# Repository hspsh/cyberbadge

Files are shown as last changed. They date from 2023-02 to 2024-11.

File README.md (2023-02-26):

# cyberbadge

Pin definitions:

| Name | Pin | Description
| --- | --- | ---
| ESP_BOOT_B1 | 0 | Sleep / User button 1 / boot into programming mode
| PROG_TX | 1 | 
| PROG_RX | 3 | 
| LIPO_VMEAS  | 15 | Connected to LiPo voltage behind 2/3 divider
| WS_OUT | 22 | WS2812 output pin
| ESP_B2 | 26 | User button 2 / boot alternative firmware
| ESP_B3 | 25 | User button 3

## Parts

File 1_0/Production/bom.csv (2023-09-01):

Comment | Designator | Footprint | LCSC
47uF/handsolder | C5 | Capacitor_SMD:C_1210_3225Metric_Pad1.33x2.70mm_HandSolder | C576521
100n | C6,C11,C12,C13,C14,C15,C16,C17,C18,C19,C20,C21,C22,C23,C24,C25,C26,C27,C28,C29,C30,C31,C32,C33,C34,C35,C36,C37,C38,C39,C40,C41,C42,C43,C44,C45,C46,C47,C48,C49,C50,C51,C52,C53,C54,C55,C56,C57,C58,C59,C60,C61,C62,C63,C64,C65,C66,C67,C68,C69,C70,C71,C72,C73,C74,C75,C76,C77,C78,C79,C80,C81,C82,C83,C84,C85,C86,C87,C88,C89,C90,C91,C92,C93,C94,C95,C96,C97,C98,C99,C100,C101,C102,C103,C104,C105,C106,C107,C108,C109,C110,C111,C112,C113,C114,C115,C116,C117,C118,C119,C120,C121,C122,C123,C124,C125,C126,C127,C128,C129,C130,C131,C132,C133,C134,C135,C136,C137,C138,C139,C140,C141,C142,C143,C144,C145,C146,C147,C148,C149,C150,C151,C152,C153,C154,C155,C156,C157,C158,C159,C160,C161,C162,C163,C164,C165,C166,C167,C168,C169,C170,C171,C172,C173,C174,C175,C176,C177,C178,C180,C181,C182,C183,C184,C185,C186,C187,C188,C189,C190,C191,C192,C193,C194,C195,C196,C197,C198,C199,C200,C201,C202,C203,C204,C205,C206,C207,C208,C209,C210,C211,C212,C213,C214,C215,C216,C217,C218,C219,C220,C221,C222,C223,C224,C225,C226,C227,C228,C229,C230,C231,C232,C233,C234,C235,C236,C237,C238,C239,C240,C241,C242,C243,C244,C245,C246,C247,C248,C249,C250,C251,C252,C253,C254,C255,C256,C257,C258,C259,C260,C261,C262,C263,C264,C265,C266,C267,C268,C269,C270,C271 | Capacitor_SMD:C_0201_0603Metric | C1525
4.7u | C7,C8,C9,C10,C179 | Capacitor_SMD:C_0402_1005Metric | C23733
LED | D1,D3,D4 | LED_SMD:LED_0603_1608Metric | C72038
WS2812B | D5,D6,D7,D8,D9,D10,D11,D12,D13,D14,D15,D16,D17,D18,D19,D20,D21,D22,D23,D24,D25,D26,D27,D28,D29,D30,D31,D32,D33,D34,D35,D36,D37,D38,D39,D40,D41,D42,D43,D44,D45,D46,D47,D48,D49,D50,D51,D52,D53,D54,D55,D56,D57,D58,D59,D60,D61,D62,D63,D64,D65,D66,D67,D68,D69,D70,D71,D72,D73,D74,D75,D76,D77,D78,D79,D80,D81,D82,D83,D84,D85,D86,D87,D88,D89,D90,D91,D92,D93,D94,D95,D96,D97,D98,D99,D100,D101,D102,D103,D104,D105,D106,D107,D108,D109,D110,D111,D112,D113,D114,D115,D116,D117,D118,D119,D120,D121,D122,D123,D124,D125,D126,D127,D128,D129,D130,D131,D132,D133,D134,D135,D136,D137,D138,D139,D140,D141,D142,D143,D144,D145,D146,D147,D148,D149,D150,D151,D152,D153,D154,D155,D156,D157,D158,D159,D160,D161,D162,D163,D164,D165,D166,D167,D168,D169,D170,D171,D172,D173,D174,D175,D176,D177,D178,D179,D180,D181,D182,D183,D184,D185,D186,D187,D188,D189,D190,D191,D192,D193,D194,D195,D196,D197,D198,D199,D200,D201,D202,D203,D204,D205,D206,D207,D208,D209,D210,D211,D212,D213,D214,D215,D216,D217,D218,D219,D220,D221,D222,D223,D224,D225,D226,D227,D228,D229,D230,D231,D232,D233,D234,D235,D236,D237,D238,D239,D240,D241,D242,D243,D244,D245,D246,D247,D248,D249,D250,D251,D252,D253,D254,D255,D256,D257,D258,D259,D260 | Critbit_lib:LED_WS2812B-2020_pinsRenumbered | C2976072
3A/slowblow | F1 | Fuse:Fuse_0603_1608Metric_Pad1.05x0.95mm_HandSolder | C553913
USB_C_Receptacle_USB2.0 | J1 | Connector_USB:USB_C_Receptacle_HRO_TYPE-C-31-M-12 | C165948
FS8205A | Q3 | Package_SO:TSSOP-8_4.4x3mm_P0.65mm | C16052
AO3401A | Q4,Q5 | Package_TO_SOT_SMD:SOT-23 | C15127
10k | R1,R2,R3,R6,R7,R8,R10,R14,R15,R18,R21 | Resistor_SMD:R_0201_0603Metric | C106225
2k | R16,R17 | Resistor_SMD:R_0603_1608Metric_Pad0.98x0.95mm_HandSolder | C22975
200 | R19 | Resistor_SMD:R_0201_0603Metric | C270359
1k | R20 | Resistor_SMD:R_0201_0603Metric | C138165
5.1k | R4,R5 | Resistor_SMD:R_0201_0603Metric | C473460
0R | R9,R11,R13 | Resistor_SMD:R_0603_1608Metric_Pad0.98x0.95mm_HandSolder | C2889381
B2 | SW1,SW5 | Button_Switch_SMD:SW_SPST_TL3342 | C318884
B1/BOOT | SW2 | Button_Switch_SMD:SW_SPST_TL3342 | C318884
SW_SPDT | SW3 | Button_Switch_SMD:SW_SPDT_PCM12 | C431541
ESP32-WROOM-32 | U3 | RF_Module:ESP32-WROOM-32 | C701342
SPX3819M5-L-3-3 | U4 | Package_TO_SOT_SMD:SOT-23-5 | C9055
BQ24073RGT | U5 | Package_DFN_QFN:VQFN-16-1EP_3x3mm_P0.5mm_EP1.6x1.6mm_ThermalVias | C15220
DW01x | U6 | Package_TO_SOT_SMD:SOT-23-6 | C351410

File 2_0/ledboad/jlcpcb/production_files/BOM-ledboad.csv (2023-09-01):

Comment | Designator | Footprint | LCSC
FM6126 | RU1,RU2,RU3,RU4,RU5,RU6 | SSOP-24_3.9x8.7mm_P0.635mm | C121618
AO3401A | Q1,Q2,Q3,Q4,Q5,Q6,Q7,Q8 | SOT-23 | C15127
100n | C1,C3 | C_0402_1005Metric | C1525
510 | R10,R11,R12,R13,R14,R9 | R_0402_1005Metric | C25123
10k | R1,R15,R16,R17,R2,R3,R4,R5,R6,R7,R8 | R_0402_1005Metric | C25744
LED_RGBA | D0_1,D0_2,D0_3,D0_4,D0_5,D0_6,D0_7,D0_8,D1,D10_1,D10_2,D10_3,D10_4,D10_5,D10_6,D10_7,D10_8,D11_1,D11_2,D11_3,D11_4,D11_5,D11_6,D11_7,D11_8,D12_1,D12_2,D12_3,D12_4,D12_5,D12_6,D12_7,D12_8,D13_1,D13_2,D13_3,D13_4,D13_5,D13_6,D13_7,D13_8,D14_1,D14_2,D14_3,D14_4,D14_5,D14_6,D14_7,D14_8,D15_1,D15_2,D15_3,D15_4,D15_5,D15_6,D15_7,D15_8,D16_1,D16_2,D16_3,D16_4,D16_5,D16_6,D16_7,D16_8,D17_1,D17_2,D17_3,D17_4,D17_5,D17_6,D17_7,D17_8,D18_1,D18_2,D18_3,D18_4,D18_5,D18_6,D18_7,D18_8,D19_1,D19_2,D19_3,D19_4,D19_5,D19_6,D19_7,D19_8,D1_1,D1_2,D1_3,D1_4,D1_5,D1_6,D1_7,D1_8,D20_1,D20_2,D20_3,D20_4,D20_5,D20_6,D20_7,D20_8,D21_1,D21_2,D21_3,D21_4,D21_5,D21_6,D21_7,D21_8,D22_1,D22_2,D22_3,D22_4,D22_5,D22_6,D22_7,D22_8,D23_1,D23_2,D23_3,D23_4,D23_5,D23_6,D23_7,D23_8,D24_1,D24_2,D24_3,D24_4,D24_5,D24_6,D24_7,D24_8,D25_1,D25_2,D25_3,D25_4,D25_5,D25_6,D25_7,D25_8,D26_1,D26_2,D26_3,D26_4,D26_5,D26_6,D26_7,D26_8,D27_1,D27_2,D27_3,D27_4,D27_5,D27_6,D27_7,D27_8,D28_1,D28_2,D28_3,D28_4,D28_5,D28_6,D28_7,D28_8,D29_1,D29_2,D29_3,D29_4,D29_5,D29_6,D29_7,D29_8,D2_1,D2_2,D2_3,D2_4,D2_5,D2_6,D2_7,D2_8,D30_1,D30_2,D30_3,D30_4,D30_5,D30_6,D30_7,D30_8,D31_1,D31_2,D31_3,D31_4,D31_5,D31_6,D31_7,D31_8,D3_1,D3_2,D3_3,D3_4,D3_5,D3_6,D3_7,D3_8,D4_1,D4_2,D4_3,D4_4,D4_5,D4_6,D4_7,D4_8,D5_1,D5_2,D5_3,D5_4,D5_5,D5_6,D5_7,D5_8,D6_1,D6_2,D6_3,D6_4,D6_5,D6_6,D6_7,D6_8,D7_1,D7_2,D7_3,D7_4,D7_5,D7_6,D7_7,D7_8,D8_1,D8_2,D8_3,D8_4,D8_5,D8_6,D8_7,D8_8,D9_1,D9_2,D9_3,D9_4,D9_5,D9_6,D9_7,D9_8 | 0606 | C2874115
2016/DNP | Y1 | Crystal_SMD_2016-4Pin_2.0x1.6mm | C3013592
10p/DNP | C7,C8 | C_0402_1005Metric | C32949
470n | C10,C2,C4,C5 | C_0402_1005Metric | C47339
STM32G070CBTx | U1 | LQFP-48_7x7mm_P0.5mm | C529338
XC6206PxxxMR | U2 | SOT-23-3 | C5446
TP | TP5 | TestPoint_Pad_D1.0mm
TP | TP7 | TestPoint_Pad_D1.0mm
TP | TP9 | TestPoint_Pad_D1.0mm
TP | TP28 | TestPoint_Pad_D1.0mm
TP | TP30 | TestPoint_Pad_D1.0mm
TP | TP31 | TestPoint_Pad_D1.0mm
TP | TP15 | TestPoint_Pad_D1.0mm
TP | TP6 | TestPoint_Pad_D1.0mm
TP | TP12 | TestPoint_Pad_D1.0mm
TP | TP29 | TestPoint_Pad_D1.0mm
TP | TP10 | TestPoint_Pad_D1.0mm
TP | TP24 | TestPoint_Pad_D1.0mm
TP | TP13 | TestPoint_Pad_D1.0mm
TP | TP26 | TestPoint_Pad_D1.0mm
TP | TP18 | TestPoint_Pad_D1.0mm
TP | TP19 | TestPoint_Pad_D1.0mm
TP | TP8 | TestPoint_Pad_D1.0mm
TP | TP16 | TestPoint_Pad_D1.0mm
TP | TP22 | TestPoint_Pad_D1.0mm
TP | TP21 | TestPoint_Pad_D1.0mm
TP | TP11 | TestPoint_Pad_D1.0mm
TP | TP25 | TestPoint_Pad_D1.0mm
TP | TP4 | TestPoint_Pad_D1.0mm
TP | TP17 | TestPoint_Pad_D1.0mm
TP | TP14 | TestPoint_Pad_D1.0mm
TP | TP2 | TestPoint_Pad_D1.0mm
TP | TP1 | TestPoint_Pad_D1.0mm
TP | TP27 | TestPoint_Pad_D1.0mm
TP | TP3 | TestPoint_Pad_D1.0mm
TP | TP23 | TestPoint_Pad_D1.0mm
TP | TP20 | TestPoint_Pad_D1.0mm
TP | TP32 | TestPoint_Pad_D1.0mm

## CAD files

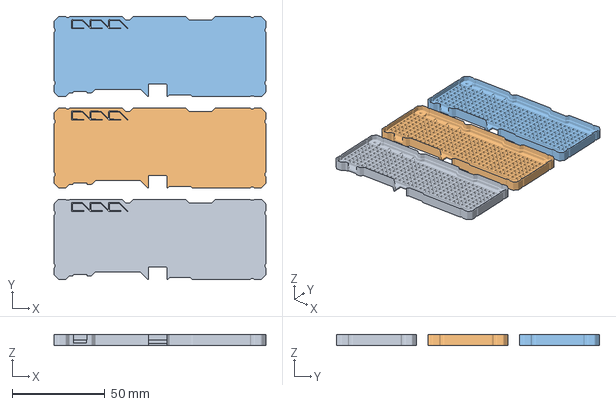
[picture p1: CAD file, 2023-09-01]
1_0/3d/diffuser.3mf
114.3 x 141.9 x 6.00 mm

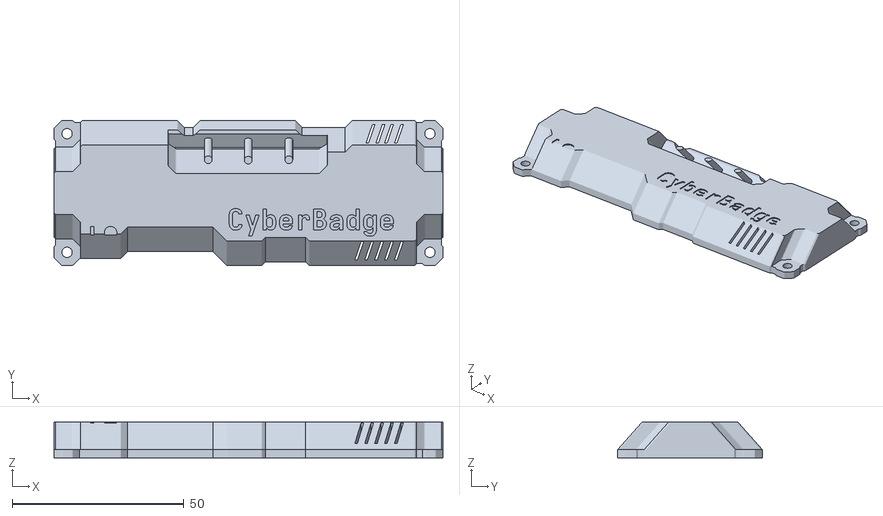
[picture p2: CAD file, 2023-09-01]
1_0/3d/filament/backcover-fat.stl
113.1 x 42.1 x 10.4

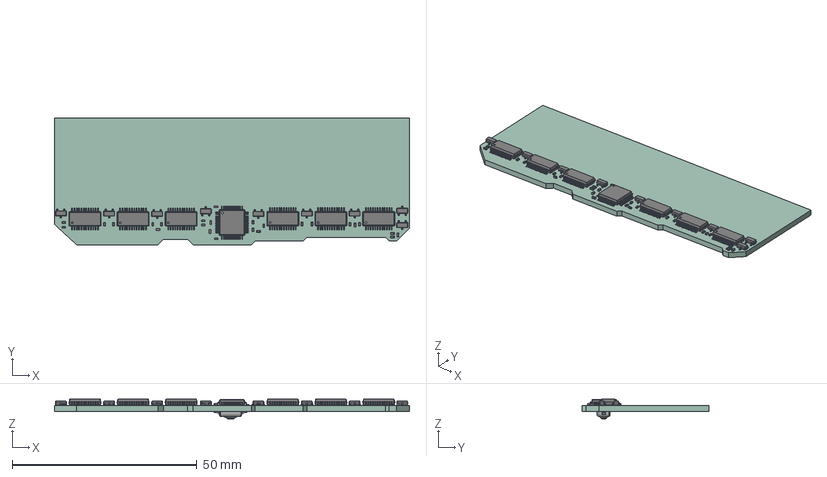
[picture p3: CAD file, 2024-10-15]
2_0/ledboad/ledboad.step
96.0 x 34.2 x 5.35 mm
SSOP_24_39x87mm_P0635mm x 6
LQFP_48_7x7mm_P05mm
SOT_23 x 8
R_0402_1005Metric x 17
C_0402_1005Metric x 8
SOT-23-3
ASSEMBLY
ledboad_PCB

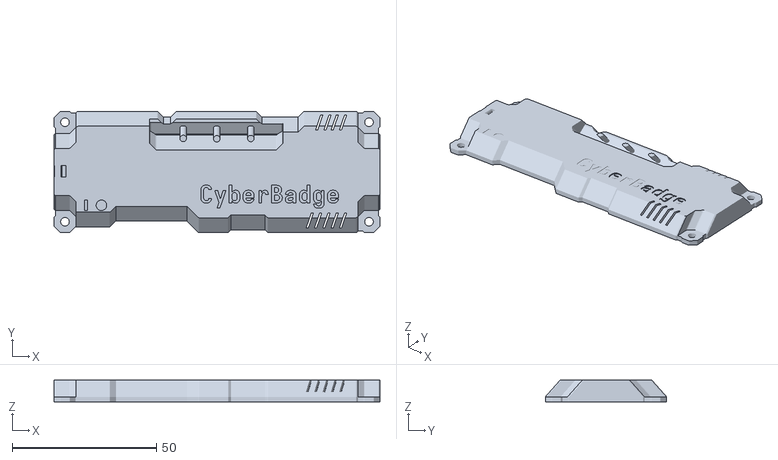
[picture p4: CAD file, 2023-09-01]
1_0/3d/filament/backcover_notch.stl
113.1 x 42.1 x 7.60

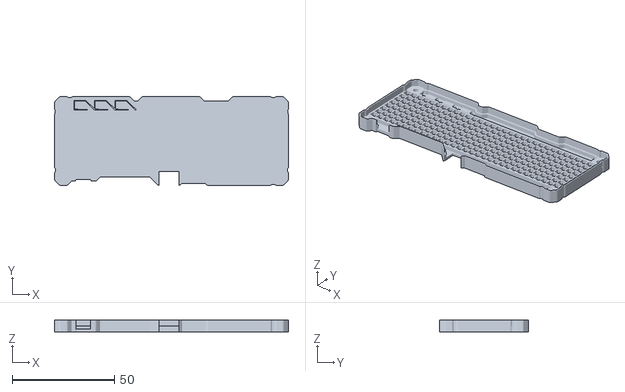
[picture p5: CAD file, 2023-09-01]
1_0/3d/filament/diffuser.stl
114.3 x 43.3 x 6.00

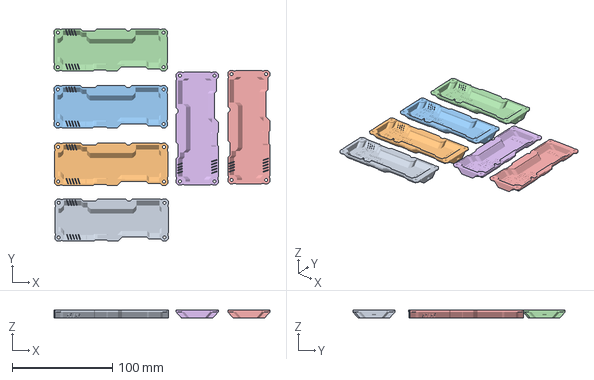
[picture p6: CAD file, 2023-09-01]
1_0/3d/filament/backcover m3.3mf
215.4 x 211.8 x 7.60 mm
backcover.stl x 6

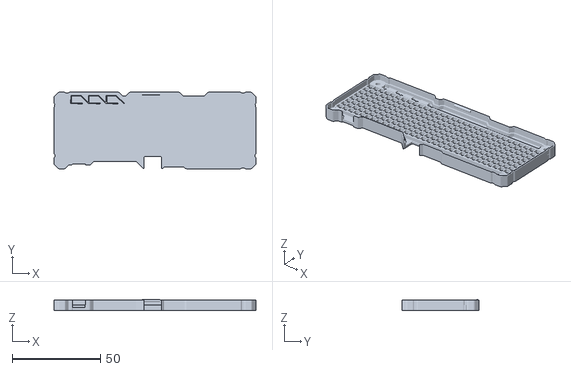
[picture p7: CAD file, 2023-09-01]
1_0/3d/filament/diffuser_notch.stl
114.3 x 43.3 x 6.10

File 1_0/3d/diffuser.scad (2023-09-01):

E = 0.6;  // Extruder dia.
L = 0.3;  // Layer height

N = 8;    // X LEDs
M = 32;   // Y LEDs

pitch = 0.350 * 10;  // dist. between leds

h = N * pitch;
w = M * pitch;

led_h = pitch;
led_w = pitch;


face_height = L*3;  // transparent diffuser face
pcb_height = 3; // PCB dist from diffures
height = pcb_height + 3;
button_height = 3 - 1.6 - 0.4;

has_holder = false;

module pcb () {
    color("green") offset(r=0.3) import("outline.svg");
}

module model () {
    #translate([65.9,110,1+pcb_height]) rotate([0,180,0]) import("model.stl");
}

module usb () {
    color("red") offset(r=0.3) import("usb.svg");
}

module switch () {
    color("red") import("switch.svg");
}


module holder () {
    color("red") offset(r=0.3) import("holder.svg");
}

module holder_holes () {
    color("red") import("holder_holes.svg");
}

module buttons () {
    color("red") offset(r=-0) import("buttons.svg");
}

module buttons_area () {
    color("red") offset(r=-0) import("buttons_area.svg");
}

module holes() {
    offset(r=-0.1) import("holes.svg");
}

module holes_standoffs () {
    color("orange") difference () {
        offset(r=1.8) import("holes.svg");
        offset(r=-0.4) import("holes.svg");
    }
}

module led() {
    square([led_w, led_h]);
}

matrix_x = 9.85;
matrix_y = 9.55;

module matrix_courtyard () {
    offset(-E/2) translate([matrix_x, matrix_y]) square([w, h]);
    //import("matrix_courtyard.svg");
}


module matrix_diffuser () {

    translate([matrix_x,matrix_y])
    for (j = [0:M-1]) {
    for (i = [0:N-1]) {
        translate([j * led_w, i * led_h, 0]) offset(r=-E/2) led();
    }
    }
    
    
}

module outer_outline(r=E) {
    offset(r=r) pcb();
}

module cover() {

    difference() {
        union() {
            linear_extrude(face_height+L)
            difference () {
                outer_outline();
                matrix_courtyard();
            }

            
            linear_extrude(pcb_height)
            union() {
                difference() {
                    outer_outline();
                    offset(r=-1) pcb();
                }
                holes_standoffs();
                offset(E*2) matrix_courtyard();
            }
            
            linear_extrude(height)
            difference() {
                outer_outline();
                pcb(); 
            }
            
        }
        color("yellow") linear_extrude(pcb_height+1)
        matrix_diffuser();
    }
    
    linear_extrude(pcb_height-button_height) color("red") buttons_area();
        
    linear_extrude(face_height) {
        matrix_courtyard();
    }
    if (!has_holder) {
        linear_extrude(face_height+L) offset(-0.5) holder();
        //linear_extrude(height+2) offset(0.4)holder_holes();
    }
}

module faceplate() {
    mirror([1,0,0]) difference () {
        color("white") cover();
        linear_extrude(height) color("red") usb();
        translate([0,0,pcb_height-1.5]) linear_extrude(5) color("red") switch();  
        if (has_holder) linear_extrude(height) color("red") holder();
        linear_extrude(height) color("red") offset(-0.2) buttons();
        //translate([18, 3.3]) linear_extrude(L) text("CyberBadge 1.0.0", size=3, font="Iosevka");
    }
}
module notch () {
translate([-73,43.5,5.4]) rotate([0,90,0]) cylinder(10,r=0.7,true, $fn=20);
}


//cover();
//model();
//faceplate();
//notch();

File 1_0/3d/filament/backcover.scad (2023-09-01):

include <diffuser.scad>

include <commit.scad>
/*skew takes an array of six angles:
 *x along y
 *x along z
 *y along x
 *y along z
 *z along x
 *z along y
 */
module skew(dims) {
matrix = [
	[ 1, dims[0]/45, dims[1]/45, 0 ],
	[ dims[2]/45, 1, dims[4]/45, 0 ],
	[ dims[5]/45, dims[3]/45, 1, 0 ],
	[ 0, 0, 0, 1 ]
];
multmatrix(matrix)
children();
}

height_back = 6*L;
hl = 5.8;

back_wall_w = 1;

module mounts_courtyard() {
    color("green") offset(r=0.4) import("mounts_courtyard.svg");
}

module holder_courtyard() {
    color("green") offset(r=0.4) import("holder_courtyard.svg");
}

module internal_supports() {
    color("green") import("internal_supports.svg");
}

module idontknow() {
    difference() {
        pcb();
        mounts_courtyard();
    }
}



module idontknow_extruded(off=0) {
    a = 40;
    intersection() {
        skew([0, 0, 0, 0, a, 0]) linear_extrude(hl) offset(off) idontknow();
        skew([0, 0, 0, 0, -a, 0]) linear_extrude(hl) offset(off)idontknow();
    }
}

module insidespace (){
    difference () {
        translate([0,0,-2*L]) idontknow_extruded(-2*E);

        linear_extrude(100, center=true) internal_supports();
    }
}

module angled_holder() {
    skew([0, 0, 0, 0, -40, 0]) linear_extrude(hl) 
        offset(0.4) holder_holes();
    intersection() {
        cube([100,100,3.]);
        skew([0, 0, 0, 0, -40, 0]) linear_extrude() pcb();
        skew([0, 0, 0, 0, 60, 0]) linear_extrude() holder_courtyard();
    }
}
module back_structure() {
    difference() {
        union() {
            linear_extrude(height_back) pcb();
            translate([0,0,height_back]) idontknow_extruded();
        }
        translate([0,0,1.5]) insidespace();
        linear_extrude(1.5) projection() insidespace();
        linear_extrude(.7) offset(.3) import("esp.svg");
    }   
    if (!has_holder) {
        translate([0,0,height_back]) angled_holder();   
    }
}

module backplate() {
    translate([0,0,height]) mirror([1,0,0]) {
        difference() {
            back_structure();
            linear_extrude() color("red") holes();
            translate([36, 4,0]) mirror([1,0,0]) linear_extrude() 
                text("/////", size=4, font="Iosevka:style=Extrabold Extended");
            translate([36, 38,0]) mirror([1,0,0]) linear_extrude() 
                text(" ////", size=4, font="Iosevka:style=Extrabold Extended");
            if (has_holder) linear_extrude(height) color("red") holder();
            translate([72, 12,height_back+hl-L]) mirror([1,0,0]) linear_extrude(L*2, true) 
                text("CyberBadge", size=6, font="Iosevka:style=Bold Extended");
            translate([0,0,height_back+hl-L]) linear_extrude(L*2, true) 
                import("onoff.svg");
            
            // strap hole
            translate([121,25,height_back+hl-1]) rotate([90,0,0]) difference() {
                cylinder(h=4, d=6, $fn=30);
                cylinder(h=10, d=3, $fn=30);
            }
            author_size = 4.5;
            author_height = hl + .7;
            translate([20,31,author_height]) linear_extrude(2*L) 
                text("2023", size=author_size, font="Iosevka:style=Extended");
            translate([20,24,author_height]) linear_extrude(2*L) 
                text("sf: Goggi", size=author_size, font="Iosevka:style=Extended");
            translate([20,17,author_height]) linear_extrude(2*L) 
                text("hw: cr1tbit", size=author_size, font="Iosevka:style=Extended");
            translate([20,10,author_height]) linear_extrude(2*L) 
                text("3d: not7CD", size=author_size, font="Iosevka:style=Extended");
            if(commit) {
                translate([105,36,author_height]) rotate([0,0,-90]) linear_extrude(2*L) 
                    text(commit, size=author_size, font="Iosevka:style=Extended");
            }
        }
    }
}



//#color("grey") faceplate();
difference() {
backplate();
    translate([0,.2,1.2]) notch();
}

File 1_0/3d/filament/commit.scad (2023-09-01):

commit="c5ee4d9";

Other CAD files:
1_0/3d/filament/backcover.3mf
1_0/3d/filament/diffuser.scad
1_0/3d/filament/backcover.stl
1_0/3d/resin/diffuser.scad

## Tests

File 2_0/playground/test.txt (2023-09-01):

(symbol (lib_id "Device:LED_RGBA") (at 0.0 0.0 180) (unit 1)
    (in_bom yes) (on_board yes) (dnp no) (fields_autoplaced)
    (uuid b5239acb-de3e-4381-ac19-cf19dd583ec6)
    (property "Reference" "D0_0" (at 0.0 -9.0 0)
        (effects (font (size 1.27 1.27)))
    )
    (property "Value" "LED_RGBA" (at 0.0 -7.0 0)
        (effects (font (size 1.27 1.27)))
    )
    (property "Footprint" "" (at 0.0 -1.0 0)
        (effects (font (size 1.27 1.27)) hide)
    )
    (property "Datasheet" "~" (at 0.0 -1.0 0)
        (effects (font (size 1.27 1.27)) hide)
    )
    (pin "1" (uuid 9afb940c-849e-4cc7-8221-d7bd8efa1177))
    (pin "2" (uuid 9dc256f7-8ff4-4ee1-883c-a23038607fed))
    (pin "3" (uuid 3aa06f76-7f2f-492b-819e-7da5531ed259))
    (pin "4" (uuid cecc442f-c784-43b3-b2a9-1cc1a514e606))
    (instances
        (project "led-panel-DCHY-P2-644-1515-VP"
            (path "/5db5c9dc-e71f-4239-bd71-746a78d23540"
                (reference "D0_0") (unit 1)
            )
        )
        (project "playground"
            (path "/bbdec91f-f69a-4b77-89e2-e7db0a42527e"
                (reference "D0_0") (unit 1)
            )
        )
    )
)
(symbol (lib_id "Device:LED_RGBA") (at 17.78 0.0 180) (unit 1)
    (in_bom yes) (on_board yes) (dnp no) (fields_autoplaced)
    (uuid 7c8bd5e9-99b7-4953-934b-2639a43ec68f)
    (property "Reference" "D1_0" (at 17.78 -9.0 0)
        (effects (font (size 1.27 1.27)))
    )
    (property "Value" "LED_RGBA" (at 17.78 -7.0 0)
        (effects (font (size 1.27 1.27)))
    )
    (property "Footprint" "" (at 17.78 -1.0 0)
        (effects (font (size 1.27 1.27)) hide)
    )
    (property "Datasheet" "~" (at 17.78 -1.0 0)
        (effects (font (size 1.27 1.27)) hide)
    )
    (pin "1" (uuid aa416f67-d0b2-45b0-9154-dd5afe01cff5))
    (pin "2" (uuid 643edd00-fd95-428d-a0bf-0b5d1236c766))
    (pin "3" (uuid 6826ec87-7cba-42d3-9d5b-8df7166d4794))
    (pin "4" (uuid 81f33f3e-a824-4fb8-ba8d-c1d81a93cd0a))
    (instances
        (project "led-panel-DCHY-P2-644-1515-VP"
            (path "/5db5c9dc-e71f-4239-bd71-746a78d23540"
                (reference "D1_0") (unit 1)
            )
        )
        (project "playground"
            (path "/bbdec91f-f69a-4b77-89e2-e7db0a42527e"
                (reference "D1_0") (unit 1)
            )
        )
    )
)
(symbol (lib_id "Device:LED_RGBA") (at 35.56 0.0 180) (unit 1)
    (in_bom yes) (on_board yes) (dnp no) (fields_autoplaced)
    (uuid 7b71219f-20d2-4035-9a9c-44744254e7f7)
    (property "Reference" "D2_0" (at 35.56 -9.0 0)
        (effects (font (size 1.27 1.27)))
    )
    (property "Value" "LED_RGBA" (at 35.56 -7.0 0)
        (effects (font (size 1.27 1.27)))
    )
    (property "Footprint" "" (at 35.56 -1.0 0)
        (effects (font (size 1.27 1.27)) hide)
    )
    (property "Datasheet" "~" (at 35.56 -1.0 0)
        (effects (font (size 1.27 1.27)) hide)
    )
    (pin "1" (uuid 90450bbe-ebfe-4208-87f5-95e08b2e7b3a))
    (pin "2" (uuid eeb8c861-fb5f-4005-9317-84928848e821))
    (pin "3" (uuid b5e12993-0491-447c-96b4-13ae09ea5589))
    (pin "4" (uuid a5530a0e-5ab4-4921-bd41-d1c1ca5cab11))
    (instances
        (project "led-panel-DCHY-P2-644-1515-VP"
            (path "/5db5c9dc-e71f-4239-bd71-746a78d23540"
                (reference "D2_0") (unit 1)
            )
        )
        (project "playground"
            (path "/bbdec91f-f69a-4b77-89e2-e7db0a42527e"
                (reference "D2_0") (unit 1)
            )
        )
    )
)
(symbol (lib_id "Device:LED_RGBA") (at 53.34 0.0 180) (unit 1)
    (in_bom yes) (on_board yes) (dnp no) (fields_autoplaced)
    (uuid bb58695b-2069-4632-bfae-99d2b3c03046)
    (property "Reference" "D3_0" (at 53.34 -9.0 0)
        (effects (font (size 1.27 1.27)))
    )
    (property "Value" "LED_RGBA" (at 53.34 -7.0 0)
        (effects (font (size 1.27 1.27)))
    )
    (property "Footprint" "" (at 53.34 -1.0 0)
        (effects (font (size 1.27 1.27)) hide)
    )
    (property "Datasheet" "~" (at 53.34 -1.0 0)
        (effects (font (size 1.27 1.27)) hide)
    )
    (pin "1" (uuid 41f23ed1-db7e-4fde-a7bd-7a3c4968526a))
    (pin "2" (uuid 2ea46015-cc32-4960-acc0-870741be18e0))
    (pin "3" (uuid 3d3d402a-1e60-4032-a4dd-b1bd28b92f42))
    (pin "4" (uuid 3bf58e80-705b-4883-bb5a-dcb5eeae0c60))
    (instances
        (project "led-panel-DCHY-P2-644-1515-VP"
            (path "/5db5c9dc-e71f-4239-bd71-746a78d23540"
                (reference "D3_0") (unit 1)
            )
        )
        (project "playground"
            (path "/bbdec91f-f69a-4b77-89e2-e7db0a42527e"
                (reference "D3_0") (unit 1)
            )
        )
    )
)
(symbol (lib_id "Device:LED_RGBA") (at 71.12 0.0 180) (unit 1)
    (in_bom yes) (on_board yes) (dnp no) (fields_autoplaced)
    (uuid 9e8b6c33-7c1f-4225-b098-66206fa557b0)
    (property "Reference" "D4_0" (at 71.12 -9.0 0)
        (effects (font (size 1.27 1.27)))
    )
    (property "Value" "LED_RGBA" (at 71.12 -7.0 0)
        (effects (font (size 1.27 1.27)))
    )
    (property "Footprint" "" (at 71.12 -1.0 0)
        (effects (font (size 1.27 1.27)) hide)
    )
    (property "Datasheet" "~" (at 71.12 -1.0 0)
        (effects (font (size 1.27 1.27)) hide)
    )
    (pin "1" (uuid 6168f4e9-d6ef-46dd-8a9a-06a26dfb000c))
    (pin "2" (uuid e317d715-ac64-40d4-806d-1ae71ec9ac4a))
    (pin "3" (uuid 34e0e496-cd19-4eec-8b63-f1335cf79731))
    (pin "4" (uuid 6fbcbc87-ce8a-4eed-b284-7ffb7634b786))
    (instances
        (project "led-panel-DCHY-P2-644-1515-VP"
            (path "/5db5c9dc-e71f-4239-bd71-746a78d23540"
                (reference "D4_0") (unit 1)
            )
        )
        (project "playground"
            (path "/bbdec91f-f69a-4b77-89e2-e7db0a42527e"
                (reference "D4_0") (unit 1)
            )
        )
    )
)
(symbol (lib_id "Device:LED_RGBA") (at 88.9 0.0 180) (unit 1)
    (in_bom yes) (on_board yes) (dnp no) (fields_autoplaced)
    (uuid c8d675de-aac9-431b-8d95-032ddd7acad7)
    (property "Reference" "D5_0" (at 88.9 -9.0 0)
        (effects (font (size 1.27 1.27)))
    )
    (property "Value" "LED_RGBA" (at 88.9 -7.0 0)
        (effects (font (size 1.27 1.27)))
    )
    (property "Footprint" "" (at 88.9 -1.0 0)
        (effects (font (size 1.27 1.27)) hide)
    )
    (property "Datasheet" "~" (at 88.9 -1.0 0)
        (effects (font (size 1.27 1.27)) hide)
    )
    (pin "1" (uuid 6f9dadc0-3249-4db3-893e-b0fa2a9106dd))
    (pin "2" (uuid 9febca0d-c065-42e7-860a-2320ac044ce0))
    (pin "3" (uuid 70a6024f-67f3-4fbc-9193-a65a6cfd7ae9))
    (pin "4" (uuid dee9dd2b-dff2-47ea-b24c-edf9b3cbe2cb))
    (instances
        (project "led-panel-DCHY-P2-644-1515-VP"
            (path "/5db5c9dc-e71f-4239-bd71-746a78d23540"
                (reference "D5_0") (unit 1)
            )
        )
        (project "playground"
            (path "/bbdec91f-f69a-4b77-89e2-e7db0a42527e"
                (reference "D5_0") (unit 1)
            )
        )
    )
)
(symbol (lib_id "Device:LED_RGBA") (at 106.68 0.0 180) (unit 1)
    (in_bom yes) (on_board yes) (dnp no) (fields_autoplaced)
    (uuid 2e2d61c4-fce4-42c1-80a6-a3d129ac2fc6)
    (property "Reference" "D6_0" (at 106.68 -9.0 0)
        (effects (font (size 1.27 1.27)))
    )
    (property "Value" "LED_RGBA" (at 106.68 -7.0 0)
        (effects (font (size 1.27 1.27)))
    )
    (property "Footprint" "" (at 106.68 -1.0 0)
        (effects (font (size 1.27 1.27)) hide)
    )
    (property "Datasheet" "~" (at 106.68 -1.0 0)
        (effects (font (size 1.27 1.27)) hide)
    )
    (pin "1" (uuid 59a1e3ae-a2fd-483b-b5f8-33efda59f700))
    (pin "2" (uuid 33c5be9b-62bb-4e88-83cd-481750cd52fc))
    (pin "3" (uuid 21321528-2ff3-48bd-97b8-fca021fb2f60))
    (pin "4" (uuid a4fefea4-8cdf-493a-aed2-c6e82a4cefcd))
    (instances
        (project "led-panel-DCHY-P2-644-1515-VP"
            (path "/5db5c9dc-e71f-4239-bd71-746a78d23540"
                (reference "D6_0") (unit 1)
            )
        )
        (project "playground"
            (path "/bbdec91f-f69a-4b77-89e2-e7db0a42527e"
                (reference "D6_0") (unit 1)
            )
        )
    )
)
(symbol (lib_id "Device:LED_RGBA") (at 124.46000000000001 0.0 180) (unit 1)
    (in_bom yes) (on_board yes) (dnp no) (fields_autoplaced)
    (uuid d1ec0869-f101-4db6-9e30-9709fad659bf)
    (property "Reference" "D7_0" (at 124.46000000000001 -9.0 0)
        (effects (font (size 1.27 1.27)))
    )
    (property "Value" "LED_RGBA" (at 124.46000000000001 -7.0 0)
        (effects (font (size 1.27 1.27)))
    )
    (property "Footprint" "" (at 124.46000000000001 -1.0 0)
        (effects (font (size 1.27 1.27)) hide)
    )
    (property "Datasheet" "~" (at 124.46000000000001 -1.0 0)
        (effects (font (size 1.27 1.27)) hide)
    )
    (pin "1" (uuid 71e733a9-78e8-4f1f-9b2d-95b119712e44))
    (pin "2" (uuid a3836047-629b-454a-aab0-2aabc785c4fd))
    (pin "3" (uuid e436dbd9-7f8d-4e15-9798-4c785a735863))
    (pin "4" (uuid e7f6f756-beb1-4a5c-8868-ace6c9972639))
    (instances
        (project "led-panel-DCHY-P2-644-1515-VP"
            (path "/5db5c9dc-e71f-4239-bd71-746a78d23540"
                (reference "D7_0") (unit 1)
            )
        )
        (project "playground"
            (path "/bbdec91f-f69a-4b77-89e2-e7db0a42527e"
                (reference "D7_0") (unit 1)
            )
        )
    )
)
(symbol (lib_id "Device:LED_RGBA") (at 142.24 0.0 180) (unit 1)
    (in_bom yes) (on_board yes) (dnp no) (fields_autoplaced)
    (uuid 18135223-a771-47a8-9ad9-08793206c02e)
    (property "Reference" "D8_0" (at 142.24 -9.0 0)
        (effects (font (size 1.27 1.27)))
    )
    (property "Value" "LED_RGBA" (at 142.24 -7.0 0)
        (effects (font (size 1.27 1.27)))
    )
    (property "Footprint" "" (at 142.24 -1.0 0)
        (effects (font (size 1.27 1.27)) hide)
    )
    (property "Datasheet" "~" (at 142.24 -1.0 0)
        (effects (font (size 1.27 1.27)) hide)
    )
    (pin "1" (uuid da6323c4-7ab3-4581-84cb-695a4334e879))
    (pin "2" (uuid d09bd3d1-8244-49f7-91e2-78c244229215))
    (pin "3" (uuid ad63bbe2-d447-4d80-9508-fc426798c51e))
    (pin "4" (uuid ef49bf94-098f-4b17-adb6-e532070caf88))
    (instances
        (project "led-panel-DCHY-P2-644-1515-VP"
            (path "/5db5c9dc-e71f-4239-bd71-746a78d23540"
                (reference "D8_0") (unit 1)
            )
        )
        (project "playground"
            (path "/bbdec91f-f69a-4b77-89e2-e7db0a42527e"
                (reference "D8_0") (unit 1)
            )
        )
    )
)
(symbol (lib_id "Device:LED_RGBA") (at 160.02 0.0 180) (unit 1)
    (in_bom yes) (on_board yes) (dnp no) (fields_autoplaced)
    (uuid 4b34109c-dba0-42f3-96b4-f39ca7909796)
    (property "Reference" "D9_0" (at 160.02 -9.0 0)
        (effects (font (size 1.27 1.27)))
    )
    (property "Value" "LED_RGBA" (at 160.02 -7.0 0)
        (effects (font (size 1.27 1.27)))
    )
    (property "Footprint" "" (at 160.02 -1.0 0)
        (effects (font (size 1.27 1.27)) hide)
    )
    (property "Datasheet" "~" (at 160.02 -1.0 0)
        (effects (font (size 1.27 1.27)) hide)
    )
    (pin "1" (uuid 86311450-1b60-4f4a-b7d7-0b5b1054a920))
    (pin "2" (uuid 144dfe6b-2bc3-440d-8526-588a9e9c6d56))
    (pin "3" (uuid e375f36c-7764-4cd0-bcad-5b4b0ed2f4ad))
    (pin "4" (uuid 5e89cbed-8687-4687-b9c3-fc662937045b))
    (instances
        (project "led-panel-DCHY-P2-644-1515-VP"
            (path "/5db5c9dc-e71f-4239-bd71-746a78d23540"
                (reference "D9_0") (unit 1)
            )
        )
        (project "playground"
            (path "/bbdec91f-f69a-4b77-89e2-e7db0a42527e"
                (reference "D9_0") (unit 1)
            )
        )
    )
)
(symbol (lib_id "Device:LED_RGBA") (at 177.8 0.0 180) (unit 1)
    (in_bom yes) (on_board yes) (dnp no) (fields_autoplaced)
    (uuid f1e571c2-d03c-4fbb-9026-2ebb28b5f4d9)
    (property "Reference" "D10_0" (at 177.8 -9.0 0)
        (effects (font (size 1.27 1.27)))
    )
    (property "Value" "LED_RGBA" (at 177.8 -7.0 0)
        (effects (font (size 1.27 1.27)))
    )
    (property "Footprint" "" (at 177.8 -1.0 0)
        (effects (font (size 1.27 1.27)) hide)
    )
    (property "Datasheet" "~" (at 177.8 -1.0 0)
        (effects (font (size 1.27 1.27)) hide)
    )
    (pin "1" (uuid 0ff5fb6b-ed1b-4bb6-b7c2-b8825612c12f))
    (pin "2" (uuid 8e362b1c-ddb5-4c50-a7ef-d50058fab5a4))
    (pin "3" (uuid 40563174-aa67-4698-a846-a652d011485c))
    (pin "4" (uuid b7262587-3ffa-463c-8c5a-ca303d3792f7))
    (instances
        (project "led-panel-DCHY-P2-644-1515-VP"
            (path "/5db5c9dc-e71f-4239-bd71-746a78d23540"
                (reference "D10_0") (unit 1)
            )
        )
        (project "playground"
            (path "/bbdec91f-f69a-4b77-89e2-e7db0a42527e"
                (reference "D10_0") (unit 1)
            )
        )
    )
)
(symbol (lib_id "Device:LED_RGBA") (at 195.58 0.0 180) (unit 1)
    (in_bom yes) (on_board yes) (dnp no) (fields_autoplaced)
    (uuid cfe18296-2c5f-4e39-9be0-daabf80e21db)
    (property "Reference" "D11_0" (at 195.58 -9.0 0)
        (effects (font (size 1.27 1.27)))
    )
    (property "Value" "LED_RGBA" (at 195.58 -7.0 0)
        (effects (font (size 1.27 1.27)))
    )
    (property "Footprint" "" (at 195.58 -1.0 0)
        (effects (font (size 1.27 1.27)) hide)
    )
    (property "Datasheet" "~" (at 195.58 -1.0 0)
        (effects (font (size 1.27 1.27)) hide)
    )
    (pin "1" (uuid cbfd824f-8265-434d-a061-ce314d1a17b8))
    (pin "2" (uuid 9c58c7f0-f652-4720-a50b-16176fcadcc8))
    (pin "3" (uuid cf3d79f7-6906-4955-846c-840bda8de959))
    (pin "4" (uuid 6f29a4dd-3184-4606-896a-7bde176deb74))
    (instances
        (project "led-panel-DCHY-P2-644-1515-VP"
            (path "/5db5c9dc-e71f-4239-bd71-746a78d23540"
                (reference "D11_0") (unit 1)
            )
        )
        (project "playground"
            (path "/bbdec91f-f69a-4b77-89e2-e7db0a42527e"
                (reference "D11_0") (unit 1)
            )
        )
    )
)
(symbol (lib_id "Device:LED_RGBA") (at 213.36 0.0 180) (unit 1)
    (in_bom yes) (on_board yes) (dnp no) (fields_autoplaced)
    (uuid 638cdb74-587b-4e95-9682-4d0ae17dec80)
    (property "Reference" "D12_0" (at 213.36 -9.0 0)
        (effects (font (size 1.27 1.27)))
    )
    (property "Value" "LED_RGBA" (at 213.36 -7.0 0)
        (effects (font (size 1.27 1.27)))
    )
    (property "Footprint" "" (at 213.36 -1.0 0)
        (effects (font (size 1.27 1.27)) hide)
    )
    (property "Datasheet" "~" (at 213.36 -1.0 0)
        (effects (font (size 1.27 1.27)) hide)
    )
    (pin "1" (uuid 63223616-e21e-4c1d-bde3-df72ff97d66a))
    (pin "2" (uuid 7d024b65-1be4-4a24-9f1f-e647cbf9387a))
    (pin "3" (uuid 93211b17-7d1a-4181-ae9f-f3df76b65c15))
    (pin "4" (uuid 66470455-c565-4bea-ac8b-f20666db9af4))
    (instances
        (project "led-panel-DCHY-P2-644-1515-VP"
            (path "/5db5c9dc-e71f-4239-bd71-746a78d23540"
                (reference "D12_0") (unit 1)
            )
        )
        (project "playground"
            (path "/bbdec91f-f69a-4b77-89e2-e7db0a42527e"
                (reference "D12_0") (unit 1)
            )
        )
    )
)
(symbol (lib_id "Device:LED_RGBA") (at 231.14000000000001 0.0 180) (unit 1)
    (in_bom yes) (on_board yes) (dnp no) (fields_autoplaced)
    (uuid 98803cc0-b2ad-4623-8544-0ee3b2ff0de2)
    (property "Reference" "D13_0" (at 231.14000000000001 -9.0 0)
        (effects (font (size 1.27 1.27)))
    )
    (property "Value" "LED_RGBA" (at 231.14000000000001 -7.0 0)
        (effects (font (size 1.27 1.27)))
    )
    (property "Footprint" "" (at 231.14000000000001 -1.0 0)
        (effects (font (size 1.27 1.27)) hide)
    )
    (property "Datasheet" "~" (at 231.14000000000001 -1.0 0)
        (effects (font (size 1.27 1.27)) hide)
    )
    (pin "1" (uuid a8911b86-052c-4c0d-aac0-253173e5f541))
    (pin "2" (uuid bad4a824-ad2e-40de-8734-d3950f4d59a7))
    (pin "3" (uuid 1606d09e-ccb2-4303-8fbf-3be10cbb1fc4))
    (pin "4" (uuid bdf62127-e66b-4f76-9d13-5da3df7d8c9a))
    (instances
        (project "led-panel-DCHY-P2-644-1515-VP"
            (path "/5db5c9dc-e71f-4239-bd71-746a78d23540"
                (reference "D13_0") (unit 1)
            )
        )
        (project "playground"
            (path "/bbdec91f-f69a-4b77-89e2-e7db0a42527e"
                (reference "D13_0") (unit 1)
            )
        )
    )
)
(symbol (lib_id "Device:LED_RGBA") (at 248.92000000000002 0.0 180) (unit 1)
    (in_bom yes) (on_board yes) (dnp no) (fields_autoplaced)
    (uuid 84c49366-4388-42bd-8da4-4313b0f25c47)
    (property "Reference" "D14_0" (at 248.92000000000002 -9.0 0)
        (effects (font (size 1.27 1.27)))
    )
    (property "Value" "LED_RGBA" (at 248.92000000000002 -7.0 0)
        (effects (font (size 1.27 1.27)))
    )
    (property "Footprint" "" (at 248.92000000000002 -1.0 0)
        (effects (font (size 1.27 1.27)) hide)
    )
    (property "Datasheet" "~" (at 248.92000000000002 -1.0 0)
        (effects (font (size 1.27 1.27)) hide)
    )
    (pin "1" (uuid 2a26a417-9a0d-4713-b4ac-c837cb0bb5ec))
    (pin "2" (uuid ef323cd7-0e29-4b2b-b5e3-87a4c2d5777e))
    (pin "3" (uuid d774bf9c-a55e-474d-b8e5-4e24857debea))
    (pin "4" (uuid 8b9993eb-0a33-4c20-8808-a22ce8c75ef1))
    (instances
        (project "led-panel-DCHY-P2-644-1515-VP"
            (path "/5db5c9dc-e71f-4239-bd71-746a78d23540"
                (reference "D14_0") (unit 1)
            )
        )
        (project "playground"
            (path "/bbdec91f-f69a-4b77-89e2-e7db0a42527e"
                (reference "D14_0") (unit 1)
            )
        )
    )
)
(symbol (lib_id "Device:LED_RGBA") (at 266.7 0.0 180) (unit 1)
    (in_bom yes) (on_board yes) (dnp no) (fields_autoplaced)
    (uuid 9ccb3a7a-08eb-4ec3-a898-c266fdd4fd63)
    (property "Reference" "D15_0" (at 266.7 -9.0 0)
        (effects (font (size 1.27 1.27)))
    )
    (property "Value" "LED_RGBA" (at 266.7 -7.0 0)
        (effects (font (size 1.27 1.27)))
    )
    (property "Footprint" "" (at 266.7 -1.0 0)
        (effects (font (size 1.27 1.27)) hide)
    )
    (property "Datasheet" "~" (at 266.7 -1.0 0)
        (effects (font (size 1.27 1.27)) hide)
    )
    (pin "1" (uuid fff66f1b-c549-4466-8a3b-5e141461b675))
    (pin "2" (uuid b22e888e-ead3-4d18-8611-3564d432eb0d))
    (pin "3" (uuid d8704b91-37c9-4f92-854c-1743acc43b54))
    (pin "4" (uuid b061771a-9e24-4e9d-a87f-50a11f47956f))
    (instances
        (project "led-panel-DCHY-P2-644-1515-VP"
            (path "/5db5c9dc-e71f-4239-bd71-746a78d23540"
                (reference "D15_0") (unit 1)
            )
        )
        (project "playground"
            (path "/bbdec91f-f69a-4b77-89e2-e7db0a42527e"
                (reference "D15_0") (unit 1)
            )
        )
    )
)
(symbol (lib_id "Device:LED_RGBA") (at 284.48 0.0 180) (unit 1)
    (in_bom yes) (on_board yes) (dnp no) (fields_autoplaced)
    (uuid ddc6de1c-22c0-49bd-8b3d-817b869bea74)
    (property "Reference" "D16_0" (at 284.48 -9.0 0)
        (effects (font (size 1.27 1.27)))
    )
    (property "Value" "LED_RGBA" (at 284.48 -7.0 0)
        (effects (font (size 1.27 1.27)))
    )
    (property "Footprint" "" (at 284.48 -1.0 0)
        (effects (font (size 1.27 1.27)) hide)
    )
    (property "Datasheet" "~" (at 284.48 -1.0 0)
        (effects (font (size 1.27 1.27)) hide)
    )
    (pin "1" (uuid b82faf44-342e-41fc-966f-651a9b69f147))
    (pin "2" (uuid 9e0516f6-473a-4eb1-82b1-c23d77248813))
    (pin "3" (uuid d674df32-7e0b-4478-a575-833059da752e))
    (pin "4" (uuid d0de94a7-82e9-44b9-ba54-d157095d2dca))
    (instances
        (project "led-panel-DCHY-P2-644-1515-VP"
            (path "/5db5c9dc-e71f-4239-bd71-746a78d23540"
                (reference "D16_0") (unit 1)
            )
        )
        (project "playground"
            (path "/bbdec91f-f69a-4b77-89e2-e7db0a42527e"
                (reference "D16_0") (unit 1)
            )
        )
    )
)
(symbol (lib_id "Device:LED_RGBA") (at 302.26 0.0 180) (unit 1)
    (in_bom yes) (on_board yes) (dnp no) (fields_autoplaced)
    (uuid 90ac0e00-6870-4570-bc46-e19dc795d811)
    (property "Reference" "D17_0" (at 302.26 -9.0 0)
        (effects (font (size 1.27 1.27)))
    )
    (property "Value" "LED_RGBA" (at 302.26 -7.0 0)
        (effects (font (size 1.27 1.27)))
    )
    (property "Footprint" "" (at 302.26 -1.0 0)
        (effects (font (size 1.27 1.27)) hide)
    )
    (property "Datasheet" "~" (at 302.26 -1.0 0)
        (effects (font (size 1.27 1.27)) hide)
    )
    (pin "1" (uuid 60225a18-0cba-47fb-83bc-2c44990057c8))
    (pin "2" (uuid 3731ceda-aa45-4800-a67a-8c1a606e73fd))
    (pin "3" (uuid c461aaa7-8ef4-4c70-a4c0-bcdfe24917ef))
    (pin "4" (uuid 89725172-08fc-4c04-b4ce-e1febaf1ae8a))
    (instances
        (project "led-panel-DCHY-P2-644-1515-VP"
            (path "/5db5c9dc-e71f-4239-bd71-746a78d23540"
                (reference "D17_0") (unit 1)
            )
        )
        (project "playground"
            (path "/bbdec91f-f69a-4b77-89e2-e7db0a42527e"
                (reference "D17_0") (unit 1)
            )
        )
    )
)
(symbol (lib_id "Device:LED_RGBA") (at 320.04 0.0 180) (unit 1)
    (in_bom yes) (on_board yes) (dnp no) (fields_autoplaced)
    (uuid 0bfcf3c9-ba43-4cd7-95e6-e1de87be6987)
    (property "Reference" "D18_0" (at 320.04 -9.0 0)
        (effects (font (size 1.27 1.27)))
    )
    (property "Value" "LED_RGBA" (at 320.04 -7.0 0)
        (effects (font (size 1.27 1.27)))
    )
    (property "Footprint" "" (at 320.04 -1.0 0)
        (effects (font (size 1.27 1.27)) hide)
    )
    (property "Datasheet" "~" (at 320.04 -1.0 0)
        (effects (font (size 1.27 1.27)) hide)
    )
    (pin "1" (uuid 263e1b26-9d17-406b-abb2-915ebaee7bf1))
    (pin "2" (uuid 6c0ff9fa-0da4-458e-8e8d-b5ae3ac570be))
    (pin "3" (uuid 603c080b-4f7f-41a3-9773-ca226aaaaebe))
    (pin "4" (uuid ed63254e-5149-4526-9a11-cf76332edeee))
    (instances
        (project "led-panel-DCHY-P2-644-1515-VP"
            (path "/5db5c9dc-e71f-4239-bd71-746a78d23540"
                (reference "D18_0") (unit 1)
            )
        )
        (project "playground"
            (path "/bbdec91f-f69a-4b77-89e2-e7db0a42527e"
                (reference "D18_0") (unit 1)
            )
        )
    )
)
(symbol (lib_id "Device:LED_RGBA") (at 337.82 0.0 180) (unit 1)
    (in_bom yes) (on_board yes) (dnp no) (fields_autoplaced)
    (uuid f86fa5d2-ac4e-473b-95d1-5ac095ec4e70)
    (property "Reference" "D19_0" (at 337.82 -9.0 0)
        (effects (font (size 1.27 1.27)))
    )
    (property "Value" "LED_RGBA" (at 337.82 -7.0 0)
        (effects (font (size 1.27 1.27)))
    )
    (property "Footprint" "" (at 337.82 -1.0 0)
        (effects (font (size 1.27 1.27)) hide)
    )
    (property "Datasheet" "~" (at 337.82 -1.0 0)
        (effects (font (size 1.27 1.27)) hide)
    )
    (pin "1" (uuid f6b88147-93e6-453b-9a11-9d283d1b4ba0))
    (pin "2" (uuid d8f40f04-914c-4b1c-ba11-125626c56eaa))
    (pin "3" (uuid 8a9d56b5-4863-44df-886b-579f3bdfd0d1))
    (pin "4" (uuid 93b979e5-1417-4a16-aa48-1cb4c1797752))
    (instances
        (project "led-panel-DCHY-P2-644-1515-VP"
            (path "/5db5c9dc-e71f-4239-bd71-746a78d23540"
                (reference "D19_0") (unit 1)
            )
        )
        (project "playground"
            (path "/bbdec91f-f69a-4b77-89e2-e7db0a42527e"
                (reference "D19_0") (unit 1)
            )
        )
    )
)
(symbol (lib_id "Device:LED_RGBA") (at 355.6 0.0 180) (unit 1)
    (in_bom yes) (on_board yes) (dnp no) (fields_autoplaced)
    (uuid 3527c40f-5bd6-4243-b007-aaa13ac5f0e1)
    (property "Reference" "D20_0" (at 355.6 -9.0 0)
        (effects (font (size 1.27 1.27)))
    )
    (property "Value" "LED_RGBA" (at 355.6 -7.0 0)
        (effects (font (size 1.27 1.27)))
    )
    (property "Footprint" "" (at 355.6 -1.0 0)
        (effects (font (size 1.27 1.27)) hide)
    )
    (property "Datasheet" "~" (at 355.6 -1.0 0)
        (effects (font (size 1.27 1.27)) hide)
    )
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

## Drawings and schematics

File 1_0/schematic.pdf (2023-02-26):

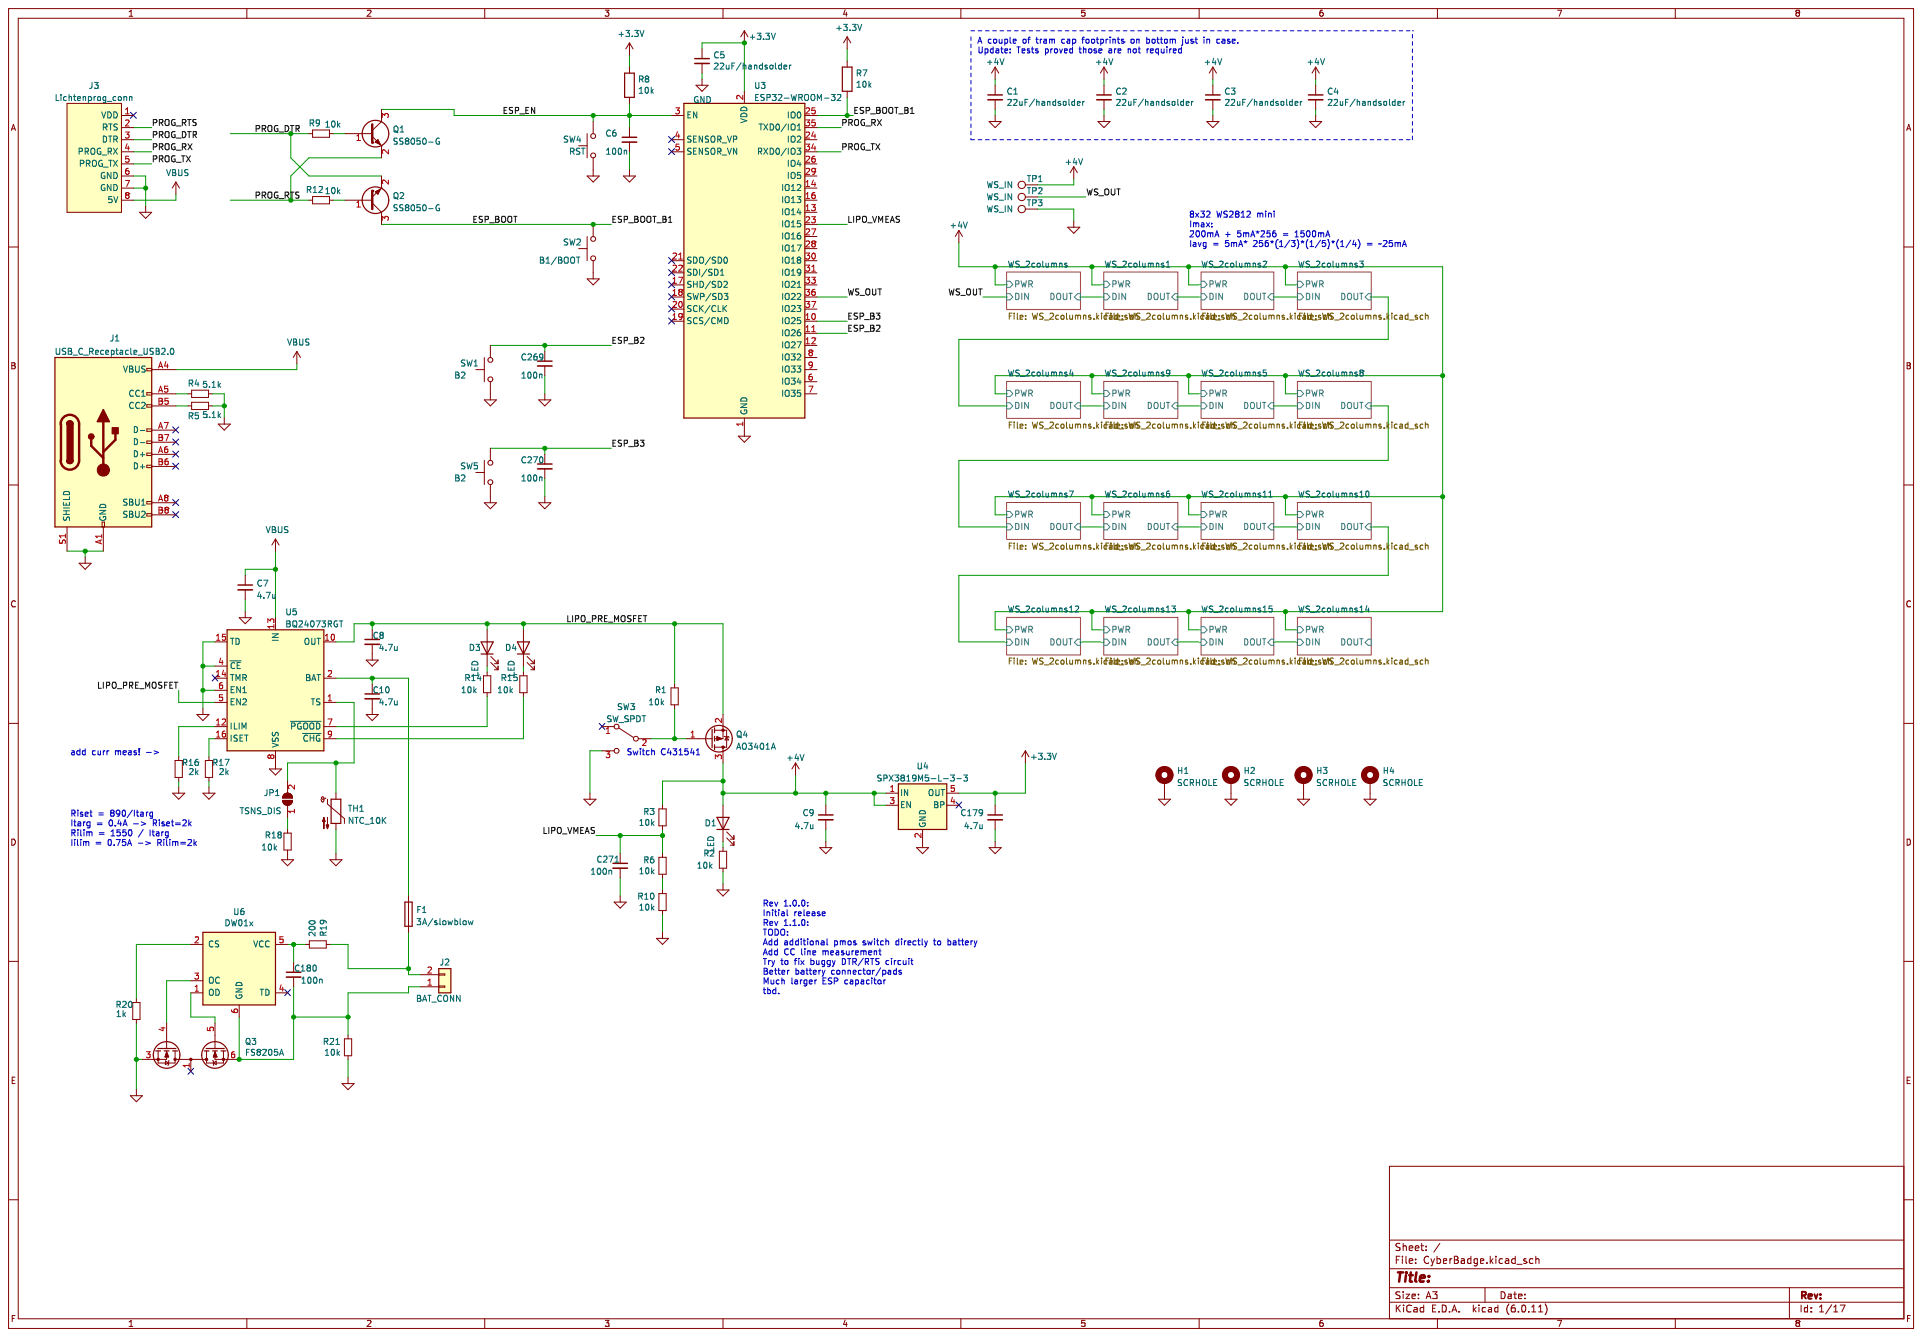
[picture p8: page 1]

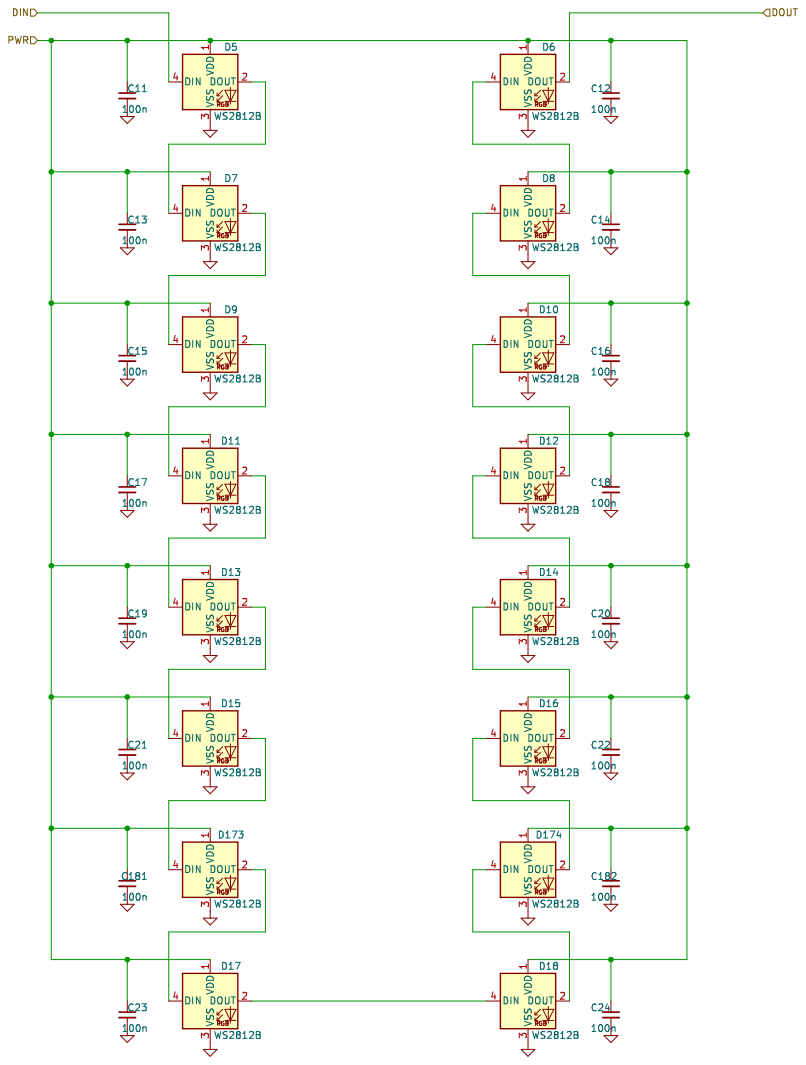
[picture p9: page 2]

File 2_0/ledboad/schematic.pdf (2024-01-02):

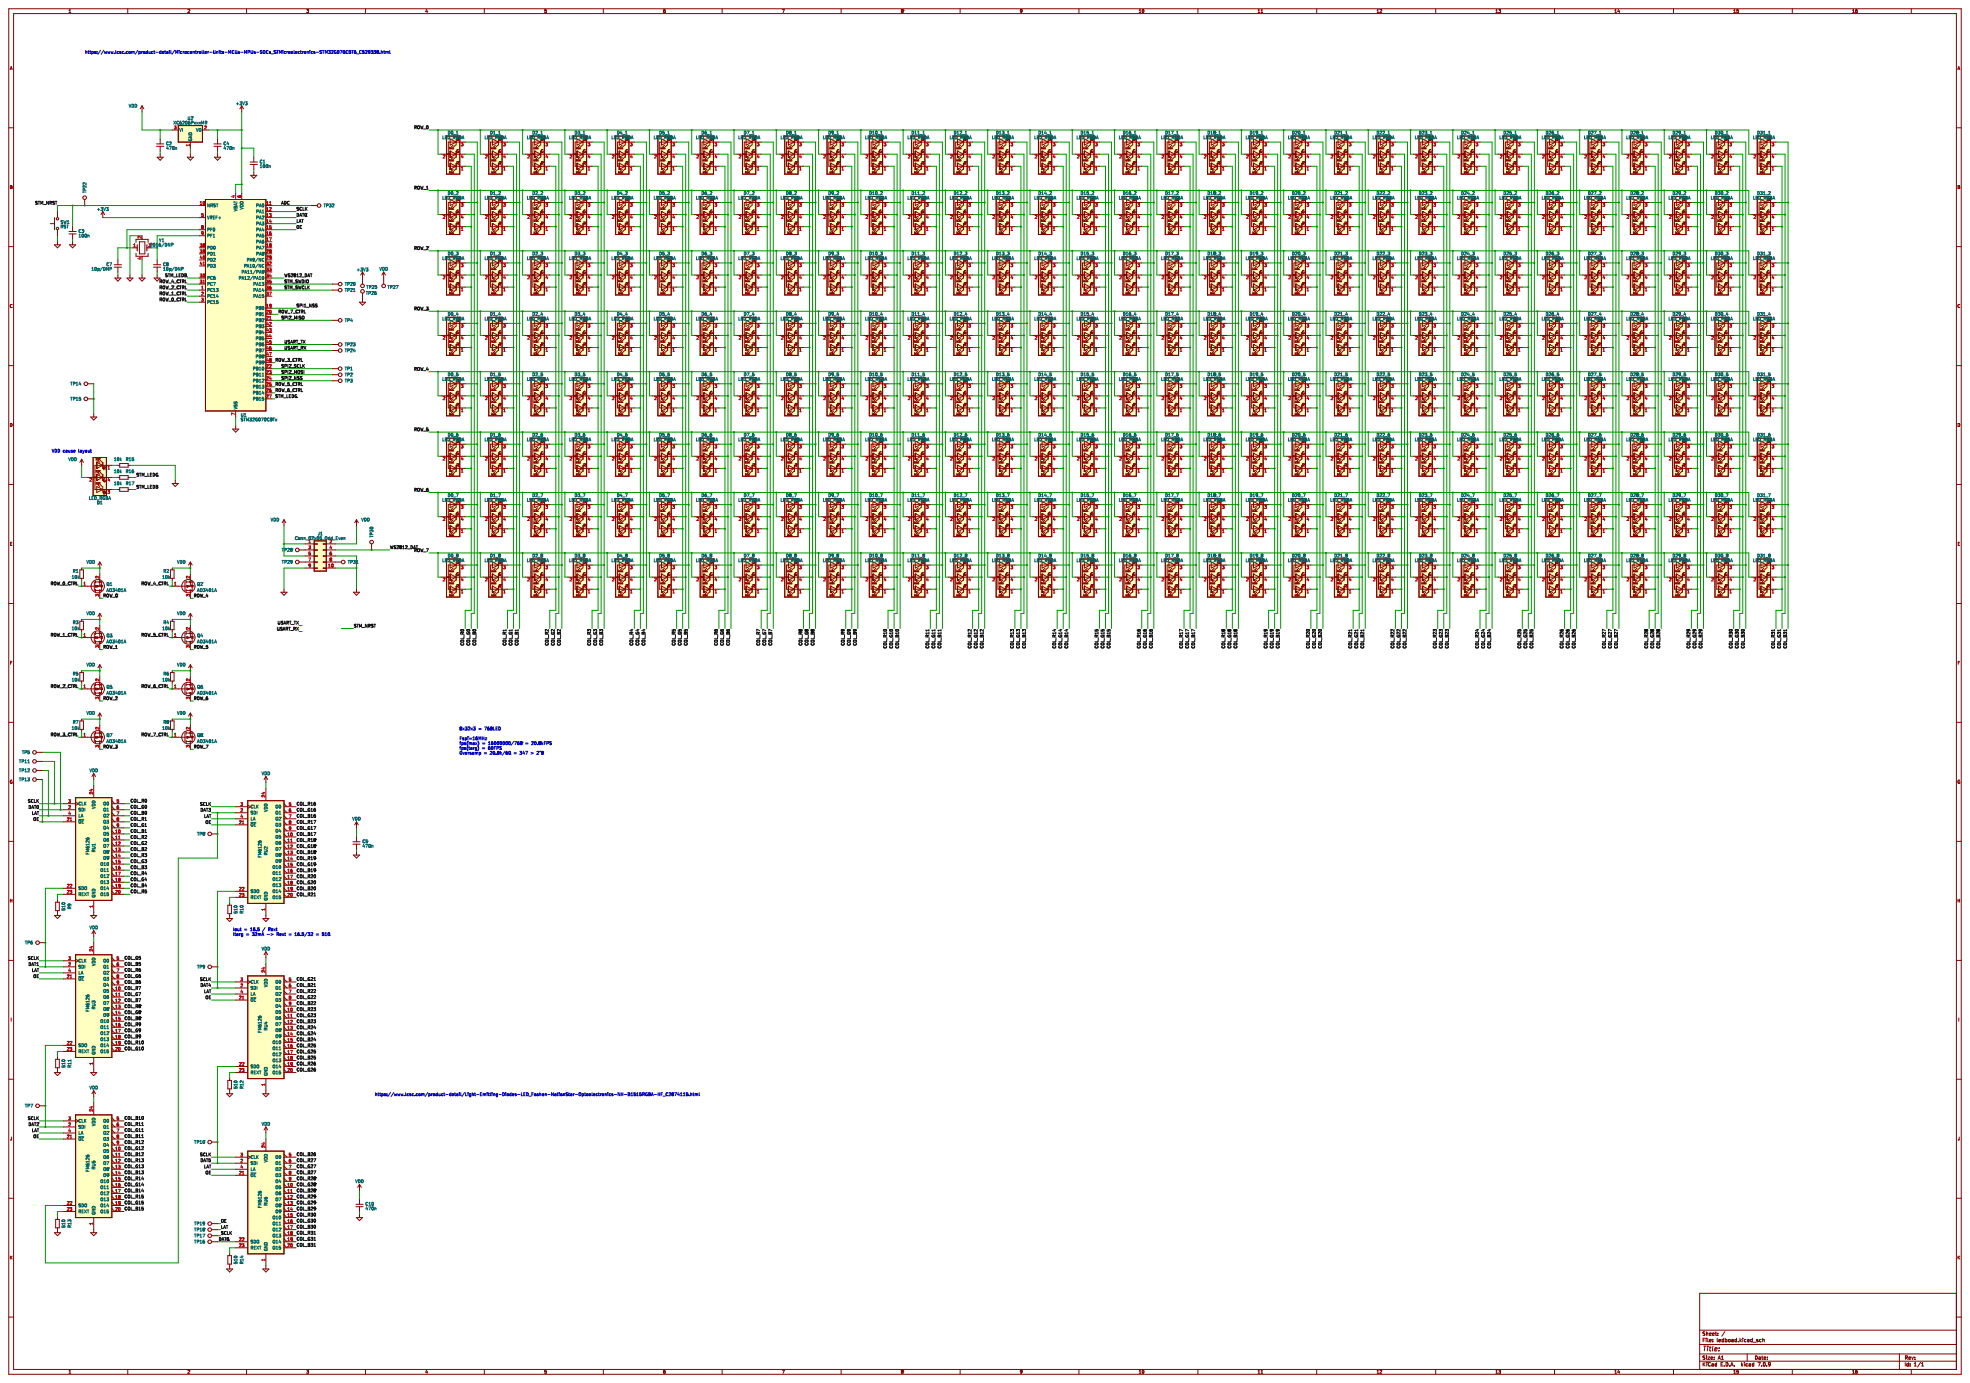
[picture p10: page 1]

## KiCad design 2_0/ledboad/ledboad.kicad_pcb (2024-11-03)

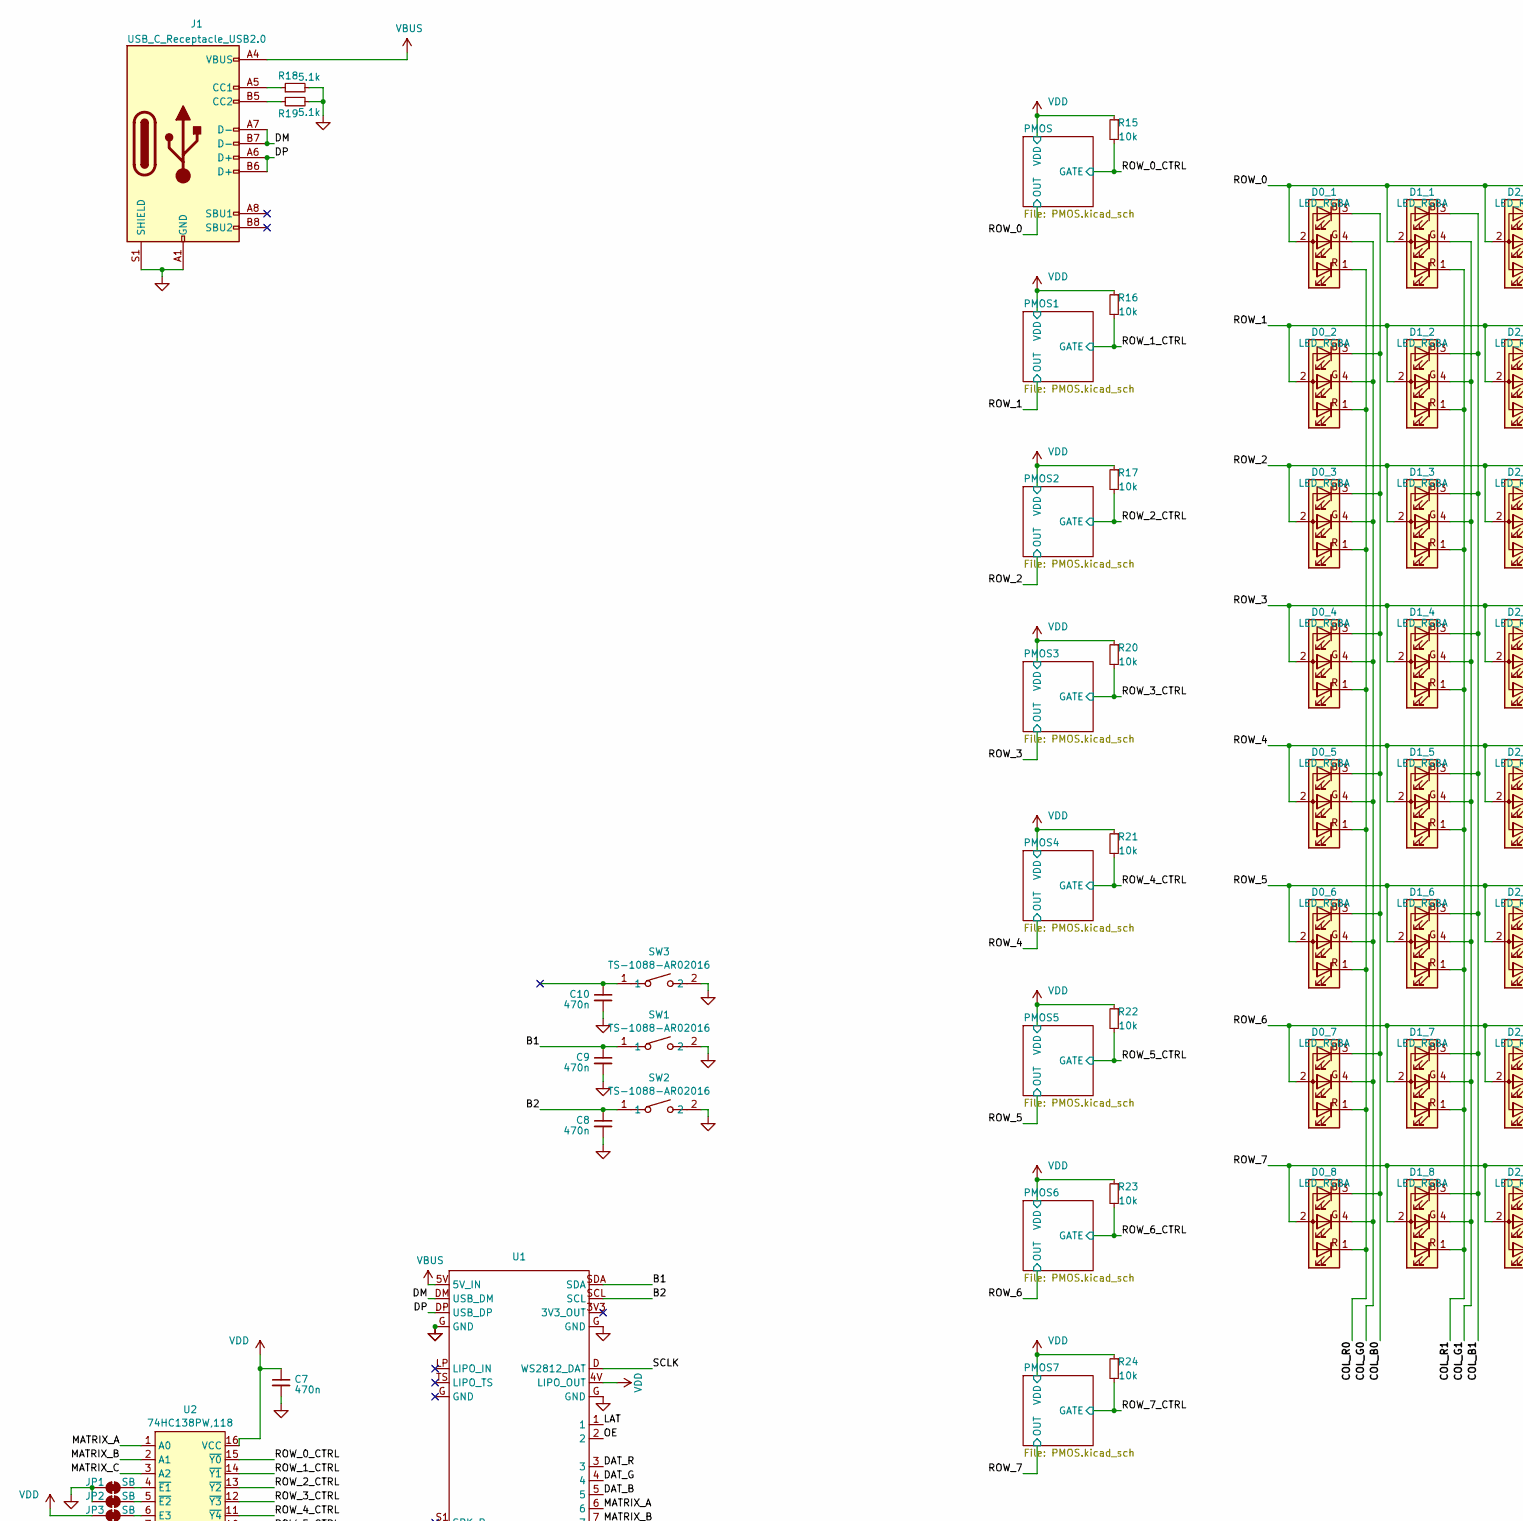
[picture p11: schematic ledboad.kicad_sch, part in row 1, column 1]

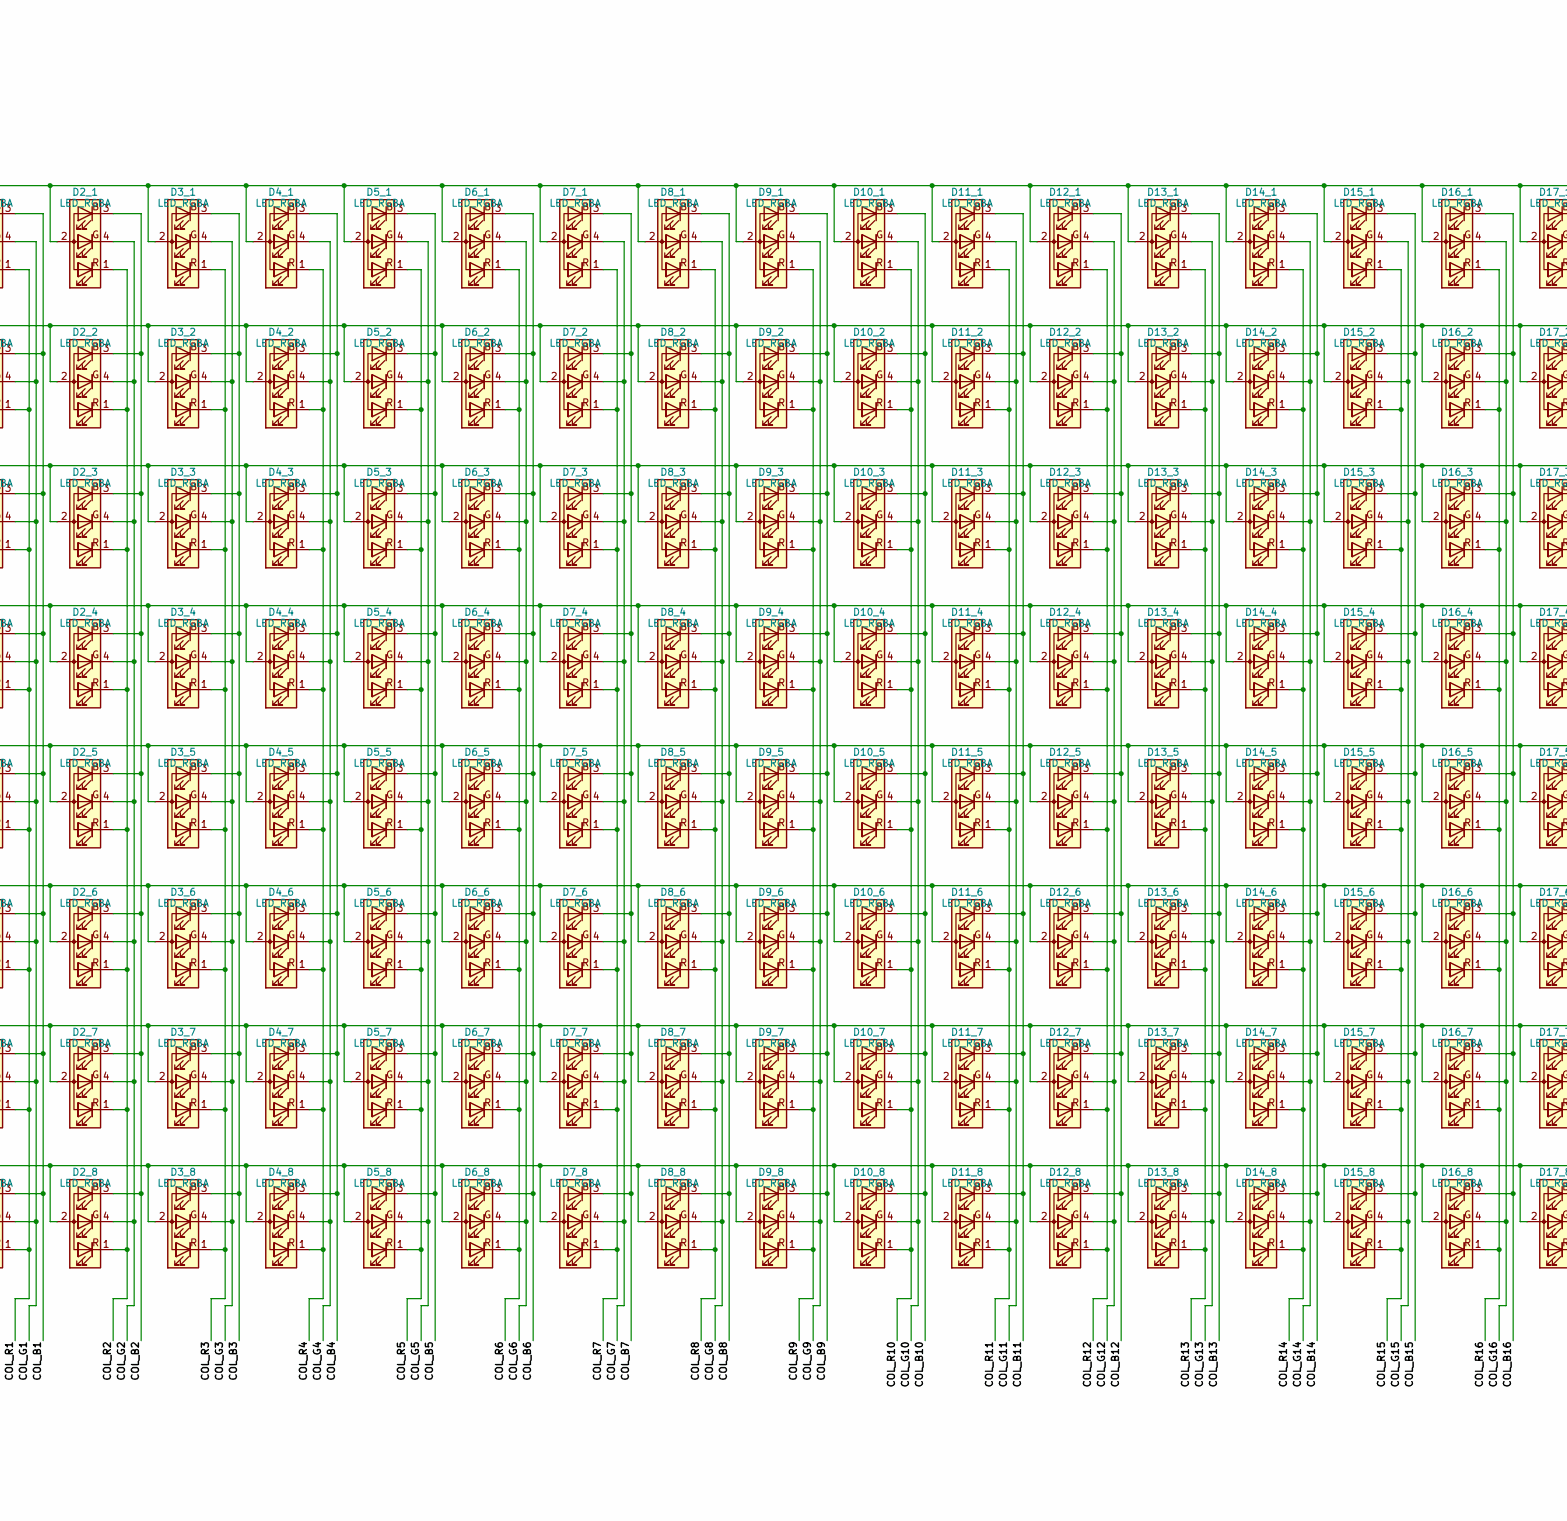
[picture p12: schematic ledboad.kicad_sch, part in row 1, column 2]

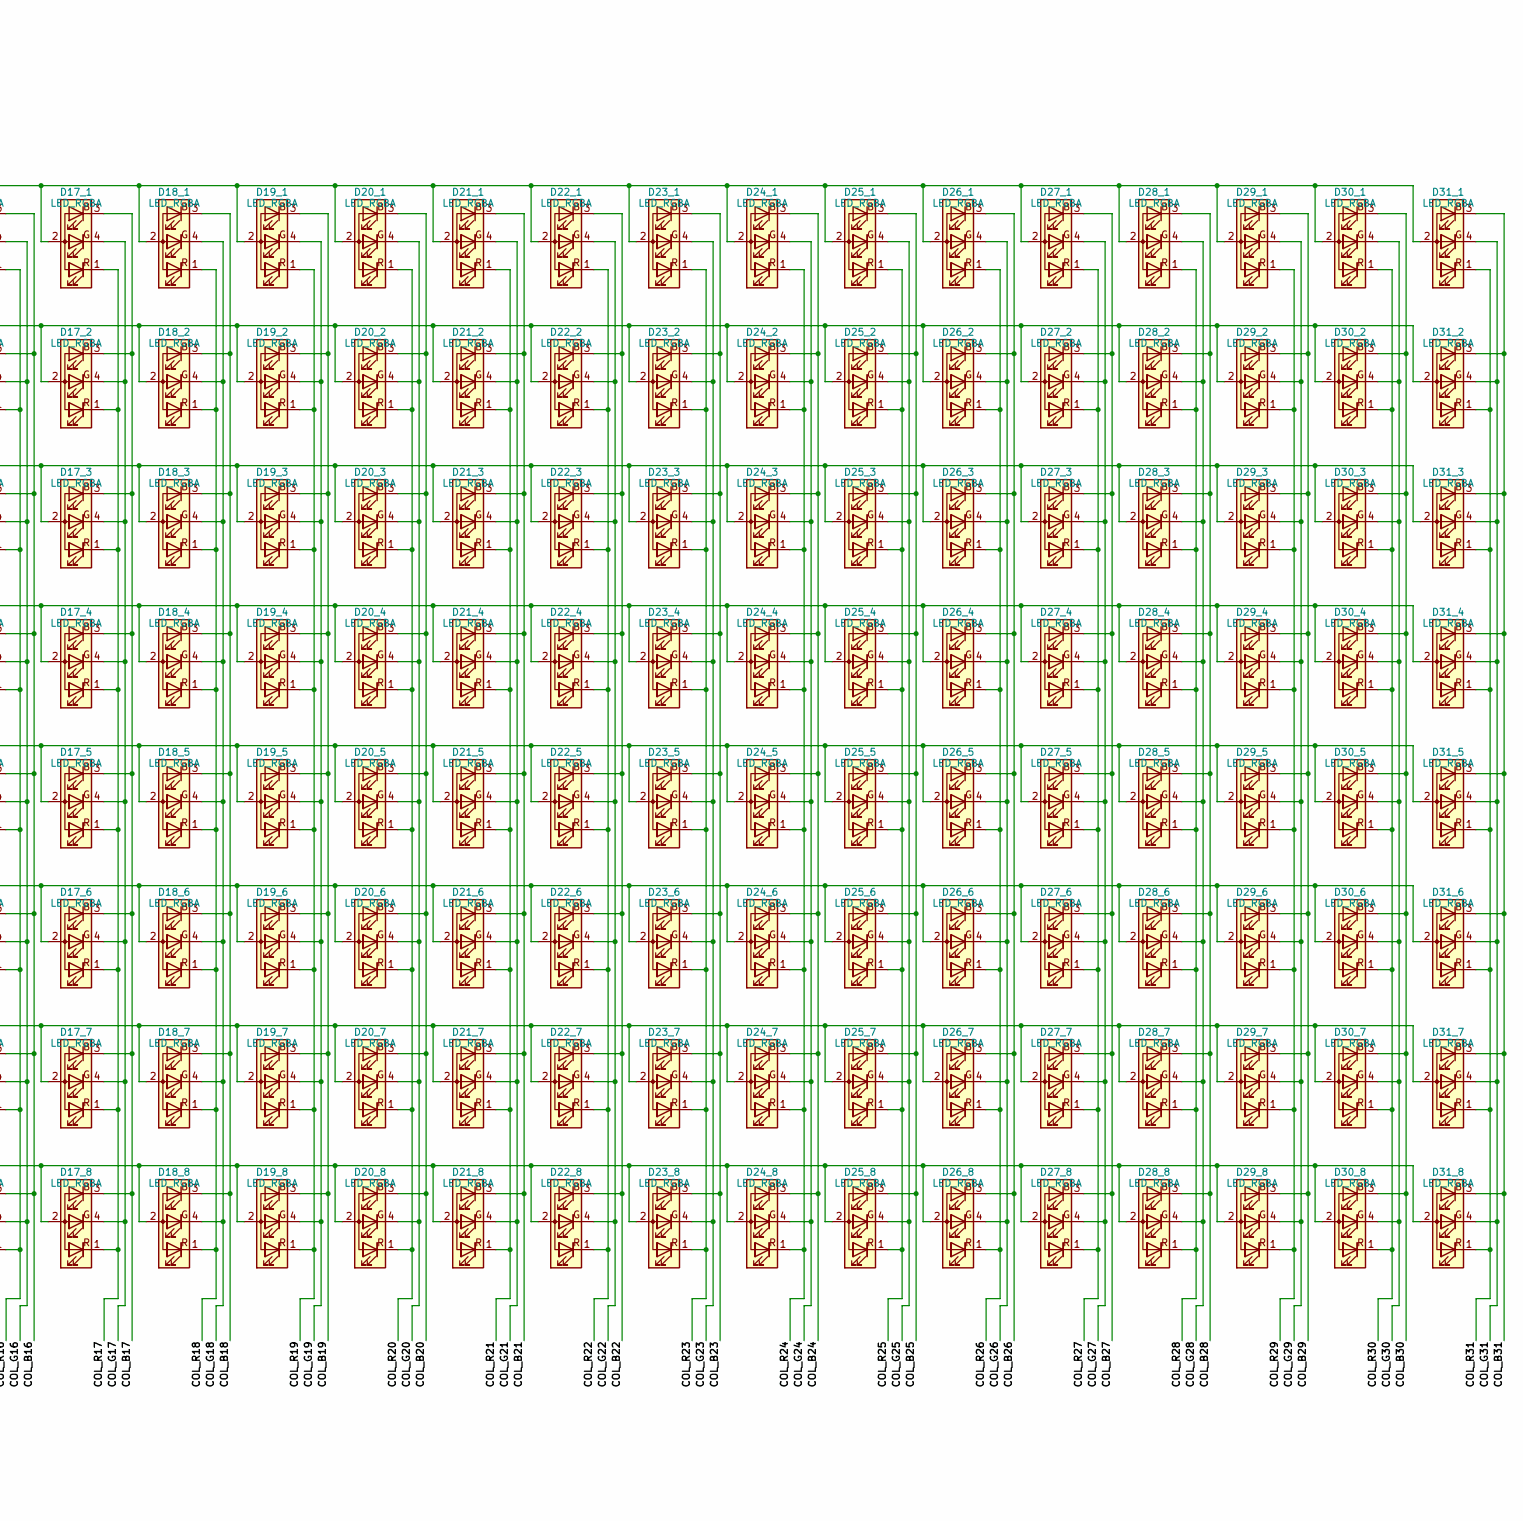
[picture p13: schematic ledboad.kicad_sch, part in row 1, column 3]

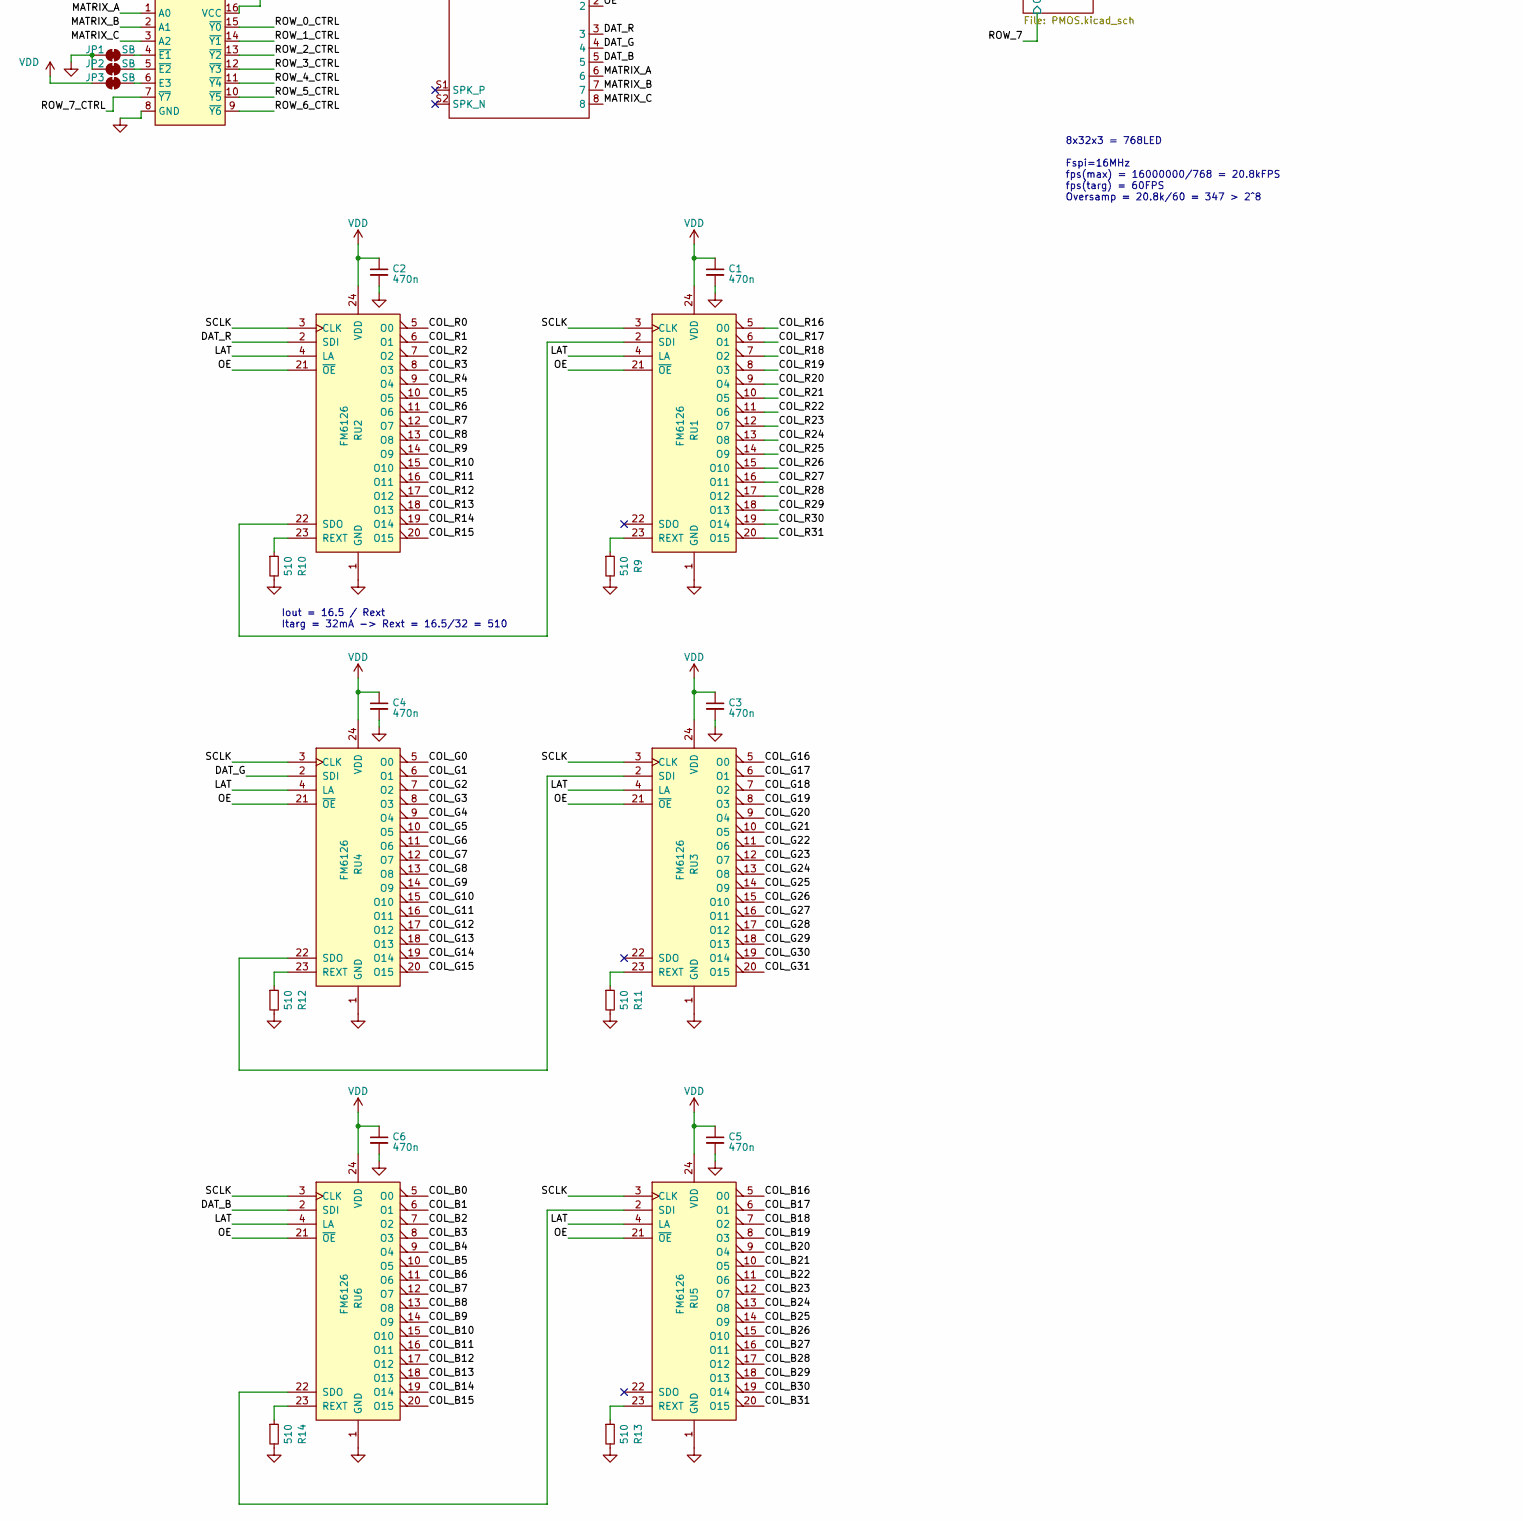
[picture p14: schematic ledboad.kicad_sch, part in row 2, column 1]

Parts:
C1, C2, C3, C4, C5, C6, C7, C8, C9, C10: 470n; C_0402_1005Metric; LCSC C52923
D0_1, D0_2, D0_3, D0_4, D0_5, D0_6, D0_7, D0_8, D1_1, D1_2, D1_3, D1_4, D1_5, D1_6, D1_7, D1_8, D2_1, D2_2, D2_3, D2_4, D2_5, D2_6, D2_7, D2_8, D3_1, D3_2, D3_3, D3_4, D3_5, D3_6, D3_7, D3_8, D4_1, D4_2, D4_3, D4_4, D4_5, D4_6, D4_7, D4_8, D5_1, D5_2, D5_3, D5_4, D5_5, D5_6, D5_7, D5_8, D6_1, D6_2, D6_3, D6_4, D6_5, D6_6, D6_7, D6_8, D7_1, D7_2, D7_3, D7_4, D7_5, D7_6, D7_7, D7_8, D8_1, D8_2, D8_3, D8_4, D8_5, D8_6, D8_7, D8_8, D9_1, D9_2, D9_3, D9_4, D9_5, D9_6, D9_7, D9_8, D10_1, D10_2, D10_3, D10_4, D10_5, D10_6, D10_7, D10_8, D11_1, D11_2, D11_3, D11_4, D11_5, D11_6, D11_7, D11_8, D12_1, D12_2, D12_3, D12_4, D12_5, D12_6, D12_7, D12_8, D13_1, D13_2, D13_3, D13_4, D13_5, D13_6, D13_7, D13_8, D14_1, D14_2, D14_3, D14_4, D14_5, D14_6, D14_7, D14_8, D15_1, D15_2, D15_3, D15_4, D15_5, D15_6, D15_7, D15_8, D16_1, D16_2, D16_3, D16_4, D16_5, D16_6, D16_7, D16_8, D17_1, D17_2, D17_3, D17_4, D17_5, D17_6, D17_7, D17_8, D18_1, D18_2, D18_3, D18_4, D18_5, D18_6, D18_7, D18_8, D19_1, D19_2, D19_3, D19_4, D19_5, D19_6, D19_7, D19_8, D20_1, D20_2, D20_3, D20_4, D20_5, D20_6, D20_7, D20_8, D21_1, D21_2, D21_3, D21_4, D21_5, D21_6, D21_7, D21_8, D22_1, D22_2, D22_3, D22_4, D22_5, D22_6, D22_7, D22_8, D23_1, D23_2, D23_3, D23_4, D23_5, D23_6, D23_7, D23_8, D24_1, D24_2, D24_3, D24_4, D24_5, D24_6, D24_7, D24_8, D25_1, D25_2, D25_3, D25_4, D25_5, D25_6, D25_7, D25_8, D26_1, D26_2, D26_3, D26_4, D26_5, D26_6, D26_7, D26_8, D27_1, D27_2, D27_3, D27_4, D27_5, D27_6, D27_7, D27_8, D28_1, D28_2, D28_3, D28_4, D28_5, D28_6, D28_7, D28_8, D29_1, D29_2, D29_3, D29_4, D29_5, D29_6, D29_7, D29_8, D30_1, D30_2, D30_3, D30_4, D30_5, D30_6, D30_7, D30_8, D31_1, D31_2, D31_3, D31_4, D31_5, D31_6, D31_7, D31_8: LED_RGBA; 0606; LCSC C2874115
J1: USB_C_Receptacle_USB2.0; USB_C_Receptacle_HRO_TYPE-C-31-M-12; LCSC C165948
JP1, JP2, JP3: SB; SolderJumper-2_P1.3mm_Bridged_RoundedPad1.0x1.5mm
R9, R10, R11, R12, R13, R14: 510; R_0402_1005Metric; LCSC C25123
R15, R16, R17, R20, R21, R22, R23, R24: 10k; R_0402_1005Metric; LCSC C25744
R18, R19: 5.1k; R_0402_1005Metric; LCSC C25905
RU1, RU2, RU3, RU4, RU5, RU6: FM6126; SSOP-24_3.9x8.7mm_P0.635mm; LCSC C121618
SW1, SW2, SW3: TS-1088-AR02016; SW-SMD_L3.9-W3.0-P4.45; LCSC C720477
U1: pilkbrain2
U2: 74HC138PW,118; SSOP-16_L6.2-W5.3-P0.65-LS7.8-BL; LCSC C47455

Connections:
/B1: C9.1, SW1.1, U1.SDA
/B2: C8.1, SW2.1, U1.SCL
/COL_B0: D0_1.3 (BK), D0_2.3 (BK), D0_3.3 (BK), D0_4.3 (BK), D0_5.3 (BK), D0_6.3 (BK), D0_7.3 (BK), D0_8.3 (BK), RU6.5 (O0)
/COL_B1: D1_1.3 (BK), D1_2.3 (BK), D1_3.3 (BK), D1_4.3 (BK), D1_5.3 (BK), D1_6.3 (BK), D1_7.3 (BK), D1_8.3 (BK), RU6.6 (O1)
/COL_B2: D2_1.3 (BK), D2_2.3 (BK), D2_3.3 (BK), D2_4.3 (BK), D2_5.3 (BK), D2_6.3 (BK), D2_7.3 (BK), D2_8.3 (BK), RU6.7 (O2)
/COL_B3: D3_1.3 (BK), D3_2.3 (BK), D3_3.3 (BK), D3_4.3 (BK), D3_5.3 (BK), D3_6.3 (BK), D3_7.3 (BK), D3_8.3 (BK), RU6.8 (O3)
/COL_B4: D4_1.3 (BK), D4_2.3 (BK), D4_3.3 (BK), D4_4.3 (BK), D4_5.3 (BK), D4_6.3 (BK), D4_7.3 (BK), D4_8.3 (BK), RU6.9 (O4)
/COL_B5: D5_1.3 (BK), D5_2.3 (BK), D5_3.3 (BK), D5_4.3 (BK), D5_5.3 (BK), D5_6.3 (BK), D5_7.3 (BK), D5_8.3 (BK), RU6.10 (O5)
/COL_B6: D6_1.3 (BK), D6_2.3 (BK), D6_3.3 (BK), D6_4.3 (BK), D6_5.3 (BK), D6_6.3 (BK), D6_7.3 (BK), D6_8.3 (BK), RU6.11 (O6)
/COL_B7: D7_1.3 (BK), D7_2.3 (BK), D7_3.3 (BK), D7_4.3 (BK), D7_5.3 (BK), D7_6.3 (BK), D7_7.3 (BK), D7_8.3 (BK), RU6.12 (O7)
/COL_B8: D8_1.3 (BK), D8_2.3 (BK), D8_3.3 (BK), D8_4.3 (BK), D8_5.3 (BK), D8_6.3 (BK), D8_7.3 (BK), D8_8.3 (BK), RU6.13 (O8)
/COL_B9: D9_1.3 (BK), D9_2.3 (BK), D9_3.3 (BK), D9_4.3 (BK), D9_5.3 (BK), D9_6.3 (BK), D9_7.3 (BK), D9_8.3 (BK), RU6.14 (O9)
/COL_B10: D10_1.3 (BK), D10_2.3 (BK), D10_3.3 (BK), D10_4.3 (BK), D10_5.3 (BK), D10_6.3 (BK), D10_7.3 (BK), D10_8.3 (BK), RU6.15 (O10)
/COL_B11: D11_1.3 (BK), D11_2.3 (BK), D11_3.3 (BK), D11_4.3 (BK), D11_5.3 (BK), D11_6.3 (BK), D11_7.3 (BK), D11_8.3 (BK), RU6.16 (O11)
/COL_B12: D12_1.3 (BK), D12_2.3 (BK), D12_3.3 (BK), D12_4.3 (BK), D12_5.3 (BK), D12_6.3 (BK), D12_7.3 (BK), D12_8.3 (BK), RU6.17 (O12)
/COL_B13: D13_1.3 (BK), D13_2.3 (BK), D13_3.3 (BK), D13_4.3 (BK), D13_5.3 (BK), D13_6.3 (BK), D13_7.3 (BK), D13_8.3 (BK), RU6.18 (O13)
/COL_B14: D14_1.3 (BK), D14_2.3 (BK), D14_3.3 (BK), D14_4.3 (BK), D14_5.3 (BK), D14_6.3 (BK), D14_7.3 (BK), D14_8.3 (BK), RU6.19 (O14)
/COL_B15: D15_1.3 (BK), D15_2.3 (BK), D15_3.3 (BK), D15_4.3 (BK), D15_5.3 (BK), D15_6.3 (BK), D15_7.3 (BK), D15_8.3 (BK), RU6.20 (O15)
/COL_B16: D16_1.3 (BK), D16_2.3 (BK), D16_3.3 (BK), D16_4.3 (BK), D16_5.3 (BK), D16_6.3 (BK), D16_7.3 (BK), D16_8.3 (BK), RU5.5 (O0)
/COL_B17: D17_1.3 (BK), D17_2.3 (BK), D17_3.3 (BK), D17_4.3 (BK), D17_5.3 (BK), D17_6.3 (BK), D17_7.3 (BK), D17_8.3 (BK), RU5.6 (O1)
/COL_B18: D18_1.3 (BK), D18_2.3 (BK), D18_3.3 (BK), D18_4.3 (BK), D18_5.3 (BK), D18_6.3 (BK), D18_7.3 (BK), D18_8.3 (BK), RU5.7 (O2)
/COL_B19: D19_1.3 (BK), D19_2.3 (BK), D19_3.3 (BK), D19_4.3 (BK), D19_5.3 (BK), D19_6.3 (BK), D19_7.3 (BK), D19_8.3 (BK), RU5.8 (O3)
/COL_B20: D20_1.3 (BK), D20_2.3 (BK), D20_3.3 (BK), D20_4.3 (BK), D20_5.3 (BK), D20_6.3 (BK), D20_7.3 (BK), D20_8.3 (BK), RU5.9 (O4)
/COL_B21: D21_1.3 (BK), D21_2.3 (BK), D21_3.3 (BK), D21_4.3 (BK), D21_5.3 (BK), D21_6.3 (BK), D21_7.3 (BK), D21_8.3 (BK), RU5.10 (O5)
/COL_B22: D22_1.3 (BK), D22_2.3 (BK), D22_3.3 (BK), D22_4.3 (BK), D22_5.3 (BK), D22_6.3 (BK), D22_7.3 (BK), D22_8.3 (BK), RU5.11 (O6)
/COL_B23: D23_1.3 (BK), D23_2.3 (BK), D23_3.3 (BK), D23_4.3 (BK), D23_5.3 (BK), D23_6.3 (BK), D23_7.3 (BK), D23_8.3 (BK), RU5.12 (O7)
/COL_B24: D24_1.3 (BK), D24_2.3 (BK), D24_3.3 (BK), D24_4.3 (BK), D24_5.3 (BK), D24_6.3 (BK), D24_7.3 (BK), D24_8.3 (BK), RU5.13 (O8)
/COL_B25: D25_1.3 (BK), D25_2.3 (BK), D25_3.3 (BK), D25_4.3 (BK), D25_5.3 (BK), D25_6.3 (BK), D25_7.3 (BK), D25_8.3 (BK), RU5.14 (O9)
/COL_B26: D26_1.3 (BK), D26_2.3 (BK), D26_3.3 (BK), D26_4.3 (BK), D26_5.3 (BK), D26_6.3 (BK), D26_7.3 (BK), D26_8.3 (BK), RU5.15 (O10)
/COL_B27: D27_1.3 (BK), D27_2.3 (BK), D27_3.3 (BK), D27_4.3 (BK), D27_5.3 (BK), D27_6.3 (BK), D27_7.3 (BK), D27_8.3 (BK), RU5.16 (O11)
/COL_B28: D28_1.3 (BK), D28_2.3 (BK), D28_3.3 (BK), D28_4.3 (BK), D28_5.3 (BK), D28_6.3 (BK), D28_7.3 (BK), D28_8.3 (BK), RU5.17 (O12)
/COL_B29: D29_1.3 (BK), D29_2.3 (BK), D29_3.3 (BK), D29_4.3 (BK), D29_5.3 (BK), D29_6.3 (BK), D29_7.3 (BK), D29_8.3 (BK), RU5.18 (O13)
/COL_B30: D30_1.3 (BK), D30_2.3 (BK), D30_3.3 (BK), D30_4.3 (BK), D30_5.3 (BK), D30_6.3 (BK), D30_7.3 (BK), D30_8.3 (BK), RU5.19 (O14)
/COL_B31: D31_1.3 (BK), D31_2.3 (BK), D31_3.3 (BK), D31_4.3 (BK), D31_5.3 (BK), D31_6.3 (BK), D31_7.3 (BK), D31_8.3 (BK), RU5.20 (O15)
/COL_G0: D0_1.4 (GK), D0_2.4 (GK), D0_3.4 (GK), D0_4.4 (GK), D0_5.4 (GK), D0_6.4 (GK), D0_7.4 (GK), D0_8.4 (GK), RU4.5 (O0)
/COL_G1: D1_1.4 (GK), D1_2.4 (GK), D1_3.4 (GK), D1_4.4 (GK), D1_5.4 (GK), D1_6.4 (GK), D1_7.4 (GK), D1_8.4 (GK), RU4.6 (O1)
/COL_G2: D2_1.4 (GK), D2_2.4 (GK), D2_3.4 (GK), D2_4.4 (GK), D2_5.4 (GK), D2_6.4 (GK), D2_7.4 (GK), D2_8.4 (GK), RU4.7 (O2)
/COL_G3: D3_1.4 (GK), D3_2.4 (GK), D3_3.4 (GK), D3_4.4 (GK), D3_5.4 (GK), D3_6.4 (GK), D3_7.4 (GK), D3_8.4 (GK), RU4.8 (O3)
/COL_G4: D4_1.4 (GK), D4_2.4 (GK), D4_3.4 (GK), D4_4.4 (GK), D4_5.4 (GK), D4_6.4 (GK), D4_7.4 (GK), D4_8.4 (GK), RU4.9 (O4)
/COL_G5: D5_1.4 (GK), D5_2.4 (GK), D5_3.4 (GK), D5_4.4 (GK), D5_5.4 (GK), D5_6.4 (GK), D5_7.4 (GK), D5_8.4 (GK), RU4.10 (O5)
/COL_G6: D6_1.4 (GK), D6_2.4 (GK), D6_3.4 (GK), D6_4.4 (GK), D6_5.4 (GK), D6_6.4 (GK), D6_7.4 (GK), D6_8.4 (GK), RU4.11 (O6)
/COL_G7: D7_1.4 (GK), D7_2.4 (GK), D7_3.4 (GK), D7_4.4 (GK), D7_5.4 (GK), D7_6.4 (GK), D7_7.4 (GK), D7_8.4 (GK), RU4.12 (O7)
/COL_G8: D8_1.4 (GK), D8_2.4 (GK), D8_3.4 (GK), D8_4.4 (GK), D8_5.4 (GK), D8_6.4 (GK), D8_7.4 (GK), D8_8.4 (GK), RU4.13 (O8)
/COL_G9: D9_1.4 (GK), D9_2.4 (GK), D9_3.4 (GK), D9_4.4 (GK), D9_5.4 (GK), D9_6.4 (GK), D9_7.4 (GK), D9_8.4 (GK), RU4.14 (O9)
/COL_G10: D10_1.4 (GK), D10_2.4 (GK), D10_3.4 (GK), D10_4.4 (GK), D10_5.4 (GK), D10_6.4 (GK), D10_7.4 (GK), D10_8.4 (GK), RU4.15 (O10)
/COL_G11: D11_1.4 (GK), D11_2.4 (GK), D11_3.4 (GK), D11_4.4 (GK), D11_5.4 (GK), D11_6.4 (GK), D11_7.4 (GK), D11_8.4 (GK), RU4.16 (O11)
/COL_G12: D12_1.4 (GK), D12_2.4 (GK), D12_3.4 (GK), D12_4.4 (GK), D12_5.4 (GK), D12_6.4 (GK), D12_7.4 (GK), D12_8.4 (GK), RU4.17 (O12)
/COL_G13: D13_1.4 (GK), D13_2.4 (GK), D13_3.4 (GK), D13_4.4 (GK), D13_5.4 (GK), D13_6.4 (GK), D13_7.4 (GK), D13_8.4 (GK), RU4.18 (O13)
/COL_G14: D14_1.4 (GK), D14_2.4 (GK), D14_3.4 (GK), D14_4.4 (GK), D14_5.4 (GK), D14_6.4 (GK), D14_7.4 (GK), D14_8.4 (GK), RU4.19 (O14)
/COL_G15: D15_1.4 (GK), D15_2.4 (GK), D15_3.4 (GK), D15_4.4 (GK), D15_5.4 (GK), D15_6.4 (GK), D15_7.4 (GK), D15_8.4 (GK), RU4.20 (O15)
/COL_G16: D16_1.4 (GK), D16_2.4 (GK), D16_3.4 (GK), D16_4.4 (GK), D16_5.4 (GK), D16_6.4 (GK), D16_7.4 (GK), D16_8.4 (GK), RU3.5 (O0)
/COL_G17: D17_1.4 (GK), D17_2.4 (GK), D17_3.4 (GK), D17_4.4 (GK), D17_5.4 (GK), D17_6.4 (GK), D17_7.4 (GK), D17_8.4 (GK), RU3.6 (O1)
/COL_G18: D18_1.4 (GK), D18_2.4 (GK), D18_3.4 (GK), D18_4.4 (GK), D18_5.4 (GK), D18_6.4 (GK), D18_7.4 (GK), D18_8.4 (GK), RU3.7 (O2)
/COL_G19: D19_1.4 (GK), D19_2.4 (GK), D19_3.4 (GK), D19_4.4 (GK), D19_5.4 (GK), D19_6.4 (GK), D19_7.4 (GK), D19_8.4 (GK), RU3.8 (O3)
/COL_G20: D20_1.4 (GK), D20_2.4 (GK), D20_3.4 (GK), D20_4.4 (GK), D20_5.4 (GK), D20_6.4 (GK), D20_7.4 (GK), D20_8.4 (GK), RU3.9 (O4)
/COL_G21: D21_1.4 (GK), D21_2.4 (GK), D21_3.4 (GK), D21_4.4 (GK), D21_5.4 (GK), D21_6.4 (GK), D21_7.4 (GK), D21_8.4 (GK), RU3.10 (O5)
/COL_G22: D22_1.4 (GK), D22_2.4 (GK), D22_3.4 (GK), D22_4.4 (GK), D22_5.4 (GK), D22_6.4 (GK), D22_7.4 (GK), D22_8.4 (GK), RU3.11 (O6)
/COL_G23: D23_1.4 (GK), D23_2.4 (GK), D23_3.4 (GK), D23_4.4 (GK), D23_5.4 (GK), D23_6.4 (GK), D23_7.4 (GK), D23_8.4 (GK), RU3.12 (O7)
/COL_G24: D24_1.4 (GK), D24_2.4 (GK), D24_3.4 (GK), D24_4.4 (GK), D24_5.4 (GK), D24_6.4 (GK), D24_7.4 (GK), D24_8.4 (GK), RU3.13 (O8)
/COL_G25: D25_1.4 (GK), D25_2.4 (GK), D25_3.4 (GK), D25_4.4 (GK), D25_5.4 (GK), D25_6.4 (GK), D25_7.4 (GK), D25_8.4 (GK), RU3.14 (O9)
/COL_G26: D26_1.4 (GK), D26_2.4 (GK), D26_3.4 (GK), D26_4.4 (GK), D26_5.4 (GK), D26_6.4 (GK), D26_7.4 (GK), D26_8.4 (GK), RU3.15 (O10)
/COL_G27: D27_1.4 (GK), D27_2.4 (GK), D27_3.4 (GK), D27_4.4 (GK), D27_5.4 (GK), D27_6.4 (GK), D27_7.4 (GK), D27_8.4 (GK), RU3.16 (O11)
/COL_G28: D28_1.4 (GK), D28_2.4 (GK), D28_3.4 (GK), D28_4.4 (GK), D28_5.4 (GK), D28_6.4 (GK), D28_7.4 (GK), D28_8.4 (GK), RU3.17 (O12)
/COL_G29: D29_1.4 (GK), D29_2.4 (GK), D29_3.4 (GK), D29_4.4 (GK), D29_5.4 (GK), D29_6.4 (GK), D29_7.4 (GK), D29_8.4 (GK), RU3.18 (O13)
/COL_G30: D30_1.4 (GK), D30_2.4 (GK), D30_3.4 (GK), D30_4.4 (GK), D30_5.4 (GK), D30_6.4 (GK), D30_7.4 (GK), D30_8.4 (GK), RU3.19 (O14)
/COL_G31: D31_1.4 (GK), D31_2.4 (GK), D31_3.4 (GK), D31_4.4 (GK), D31_5.4 (GK), D31_6.4 (GK), D31_7.4 (GK), D31_8.4 (GK), RU3.20 (O15)
/COL_R0: D0_1.1 (RK), D0_2.1 (RK), D0_3.1 (RK), D0_4.1 (RK), D0_5.1 (RK), D0_6.1 (RK), D0_7.1 (RK), D0_8.1 (RK), RU2.5 (O0)
/COL_R1: D1_1.1 (RK), D1_2.1 (RK), D1_3.1 (RK), D1_4.1 (RK), D1_5.1 (RK), D1_6.1 (RK), D1_7.1 (RK), D1_8.1 (RK), RU2.6 (O1)
/COL_R2: D2_1.1 (RK), D2_2.1 (RK), D2_3.1 (RK), D2_4.1 (RK), D2_5.1 (RK), D2_6.1 (RK), D2_7.1 (RK), D2_8.1 (RK), RU2.7 (O2)
/COL_R3: D3_1.1 (RK), D3_2.1 (RK), D3_3.1 (RK), D3_4.1 (RK), D3_5.1 (RK), D3_6.1 (RK), D3_7.1 (RK), D3_8.1 (RK), RU2.8 (O3)
/COL_R4: D4_1.1 (RK), D4_2.1 (RK), D4_3.1 (RK), D4_4.1 (RK), D4_5.1 (RK), D4_6.1 (RK), D4_7.1 (RK), D4_8.1 (RK), RU2.9 (O4)
/COL_R5: D5_1.1 (RK), D5_2.1 (RK), D5_3.1 (RK), D5_4.1 (RK), D5_5.1 (RK), D5_6.1 (RK), D5_7.1 (RK), D5_8.1 (RK), RU2.10 (O5)
/COL_R6: D6_1.1 (RK), D6_2.1 (RK), D6_3.1 (RK), D6_4.1 (RK), D6_5.1 (RK), D6_6.1 (RK), D6_7.1 (RK), D6_8.1 (RK), RU2.11 (O6)
/COL_R7: D7_1.1 (RK), D7_2.1 (RK), D7_3.1 (RK), D7_4.1 (RK), D7_5.1 (RK), D7_6.1 (RK), D7_7.1 (RK), D7_8.1 (RK), RU2.12 (O7)
/COL_R8: D8_1.1 (RK), D8_2.1 (RK), D8_3.1 (RK), D8_4.1 (RK), D8_5.1 (RK), D8_6.1 (RK), D8_7.1 (RK), D8_8.1 (RK), RU2.13 (O8)
/COL_R9: D9_1.1 (RK), D9_2.1 (RK), D9_3.1 (RK), D9_4.1 (RK), D9_5.1 (RK), D9_6.1 (RK), D9_7.1 (RK), D9_8.1 (RK), RU2.14 (O9)
/COL_R10: D10_1.1 (RK), D10_2.1 (RK), D10_3.1 (RK), D10_4.1 (RK), D10_5.1 (RK), D10_6.1 (RK), D10_7.1 (RK), D10_8.1 (RK), RU2.15 (O10)
/COL_R11: D11_1.1 (RK), D11_2.1 (RK), D11_3.1 (RK), D11_4.1 (RK), D11_5.1 (RK), D11_6.1 (RK), D11_7.1 (RK), D11_8.1 (RK), RU2.16 (O11)
/COL_R12: D12_1.1 (RK), D12_2.1 (RK), D12_3.1 (RK), D12_4.1 (RK), D12_5.1 (RK), D12_6.1 (RK), D12_7.1 (RK), D12_8.1 (RK), RU2.17 (O12)
/COL_R13: D13_1.1 (RK), D13_2.1 (RK), D13_3.1 (RK), D13_4.1 (RK), D13_5.1 (RK), D13_6.1 (RK), D13_7.1 (RK), D13_8.1 (RK), RU2.18 (O13)
/COL_R14: D14_1.1 (RK), D14_2.1 (RK), D14_3.1 (RK), D14_4.1 (RK), D14_5.1 (RK), D14_6.1 (RK), D14_7.1 (RK), D14_8.1 (RK), RU2.19 (O14)
/COL_R15: D15_1.1 (RK), D15_2.1 (RK), D15_3.1 (RK), D15_4.1 (RK), D15_5.1 (RK), D15_6.1 (RK), D15_7.1 (RK), D15_8.1 (RK), RU2.20 (O15)
/COL_R16: D16_1.1 (RK), D16_2.1 (RK), D16_3.1 (RK), D16_4.1 (RK), D16_5.1 (RK), D16_6.1 (RK), D16_7.1 (RK), D16_8.1 (RK), RU1.5 (O0)
/COL_R17: D17_1.1 (RK), D17_2.1 (RK), D17_3.1 (RK), D17_4.1 (RK), D17_5.1 (RK), D17_6.1 (RK), D17_7.1 (RK), D17_8.1 (RK), RU1.6 (O1)
/COL_R18: D18_1.1 (RK), D18_2.1 (RK), D18_3.1 (RK), D18_4.1 (RK), D18_5.1 (RK), D18_6.1 (RK), D18_7.1 (RK), D18_8.1 (RK), RU1.7 (O2)
/COL_R19: D19_1.1 (RK), D19_2.1 (RK), D19_3.1 (RK), D19_4.1 (RK), D19_5.1 (RK), D19_6.1 (RK), D19_7.1 (RK), D19_8.1 (RK), RU1.8 (O3)
/COL_R20: D20_1.1 (RK), D20_2.1 (RK), D20_3.1 (RK), D20_4.1 (RK), D20_5.1 (RK), D20_6.1 (RK), D20_7.1 (RK), D20_8.1 (RK), RU1.9 (O4)
/COL_R21: D21_1.1 (RK), D21_2.1 (RK), D21_3.1 (RK), D21_4.1 (RK), D21_5.1 (RK), D21_6.1 (RK), D21_7.1 (RK), D21_8.1 (RK), RU1.10 (O5)
/COL_R22: D22_1.1 (RK), D22_2.1 (RK), D22_3.1 (RK), D22_4.1 (RK), D22_5.1 (RK), D22_6.1 (RK), D22_7.1 (RK), D22_8.1 (RK), RU1.11 (O6)
/COL_R23: D23_1.1 (RK), D23_2.1 (RK), D23_3.1 (RK), D23_4.1 (RK), D23_5.1 (RK), D23_6.1 (RK), D23_7.1 (RK), D23_8.1 (RK), RU1.12 (O7)
/COL_R24: D24_1.1 (RK), D24_2.1 (RK), D24_3.1 (RK), D24_4.1 (RK), D24_5.1 (RK), D24_6.1 (RK), D24_7.1 (RK), D24_8.1 (RK), RU1.13 (O8)
/COL_R25: D25_1.1 (RK), D25_2.1 (RK), D25_3.1 (RK), D25_4.1 (RK), D25_5.1 (RK), D25_6.1 (RK), D25_7.1 (RK), D25_8.1 (RK), RU1.14 (O9)
/COL_R26: D26_1.1 (RK), D26_2.1 (RK), D26_3.1 (RK), D26_4.1 (RK), D26_5.1 (RK), D26_6.1 (RK), D26_7.1 (RK), D26_8.1 (RK), RU1.15 (O10)
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

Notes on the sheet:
https://www.lcsc.com/product-detail/Light-Emitting-Diodes-LED_Foshan-NationStar-Optoelectronics-NH-B1515RGBA-HF_C2874115.html
Iout = 16.5 / Rext Itarg = 32mA -> Rext = 16.5/32 = 510
8x32x3 = 768LED Fspi=16MHz fps(max) = 16000000/768 = 20.8kFPS fps(targ) = 60FPS Oversamp = 20.8k/60 = 347 > 2^8

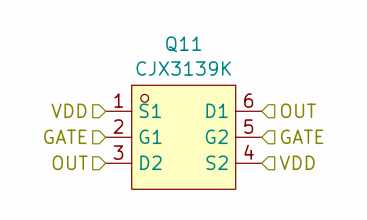
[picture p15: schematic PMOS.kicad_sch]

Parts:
Q11: CJX3139K; SOT-563_L1.6-W1.2-P0.50-LS1.6-BR; LCSC C504144

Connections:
/ROW_2: Q11.3 (D2), Q11.6 (D1); also elsewhere on the board
/ROW_2_CTRL: Q11.2 (G1), Q11.5 (G2); also elsewhere on the board
VDD: Q11.1 (S1), Q11.4 (S2); also elsewhere on the board

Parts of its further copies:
Q9, Q10, Q12, Q13, Q14, Q15, Q16: CJX3139K; SOT-563_L1.6-W1.2-P0.50-LS1.6-BR; LCSC C504144

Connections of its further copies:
/ROW_0: Q9.3 (D2), Q9.6 (D1); also elsewhere on the board
/ROW_0_CTRL: Q9.2 (G1), Q9.5 (G2); also elsewhere on the board
/ROW_1: Q10.3 (D2), Q10.6 (D1); also elsewhere on the board
/ROW_1_CTRL: Q10.2 (G1), Q10.5 (G2); also elsewhere on the board
/ROW_3: Q12.3 (D2), Q12.6 (D1); also elsewhere on the board
/ROW_3_CTRL: Q12.2 (G1), Q12.5 (G2); also elsewhere on the board
/ROW_4: Q13.3 (D2), Q13.6 (D1); also elsewhere on the board
/ROW_4_CTRL: Q13.2 (G1), Q13.5 (G2); also elsewhere on the board
/ROW_5: Q14.3 (D2), Q14.6 (D1); also elsewhere on the board
/ROW_5_CTRL: Q14.2 (G1), Q14.5 (G2); also elsewhere on the board
/ROW_6: Q15.3 (D2), Q15.6 (D1); also elsewhere on the board
/ROW_6_CTRL: Q15.2 (G1), Q15.5 (G2); also elsewhere on the board
/ROW_7: Q16.3 (D2), Q16.6 (D1); also elsewhere on the board
/ROW_7_CTRL: Q16.2 (G1), Q16.5 (G2); also elsewhere on the board
VDD: Q9.1 (S1), Q9.4 (S2), Q10.1 (S1), Q10.4 (S2), Q12.1 (S1), Q12.4 (S2), Q13.1 (S1), Q13.4 (S2), Q14.1 (S1), Q14.4 (S2), Q15.1 (S1), Q15.4 (S2), Q16.1 (S1), Q16.4 (S2); also elsewhere on the board

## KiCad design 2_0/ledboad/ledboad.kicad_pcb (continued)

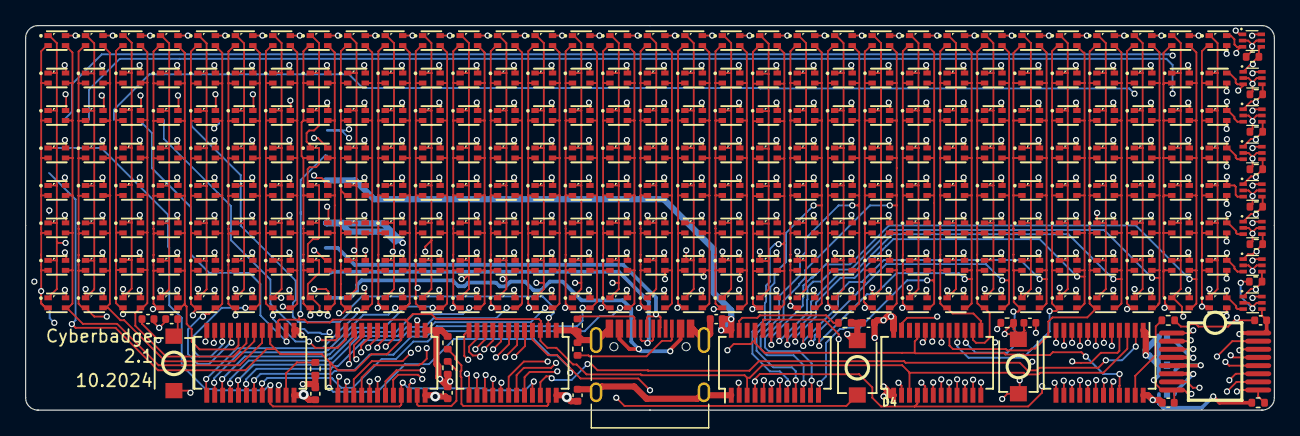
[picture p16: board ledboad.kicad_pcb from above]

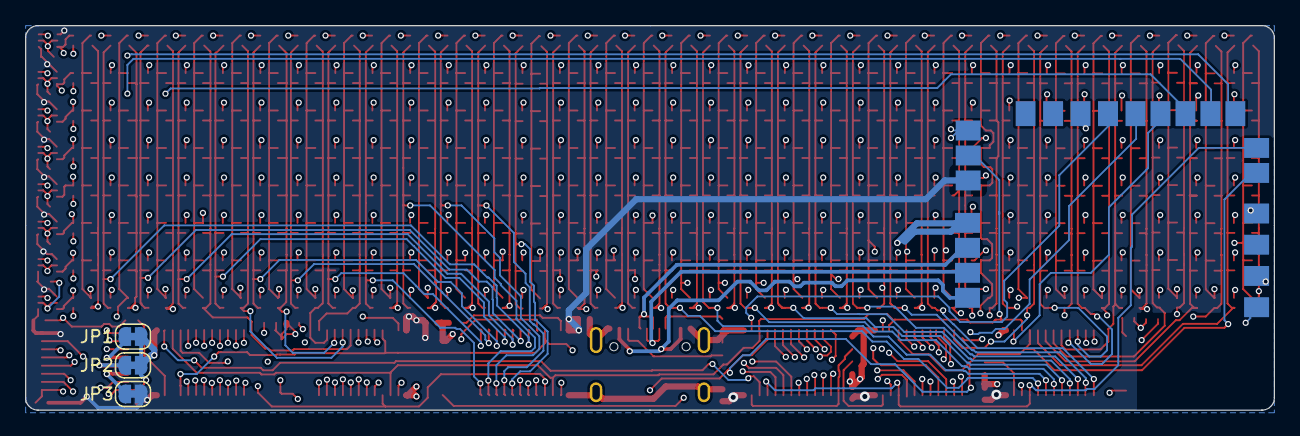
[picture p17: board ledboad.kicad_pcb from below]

Board: 4 copper layers, 100.0 x 30.8 mm, 305 parts (4 on the bottom side), 142 nets.

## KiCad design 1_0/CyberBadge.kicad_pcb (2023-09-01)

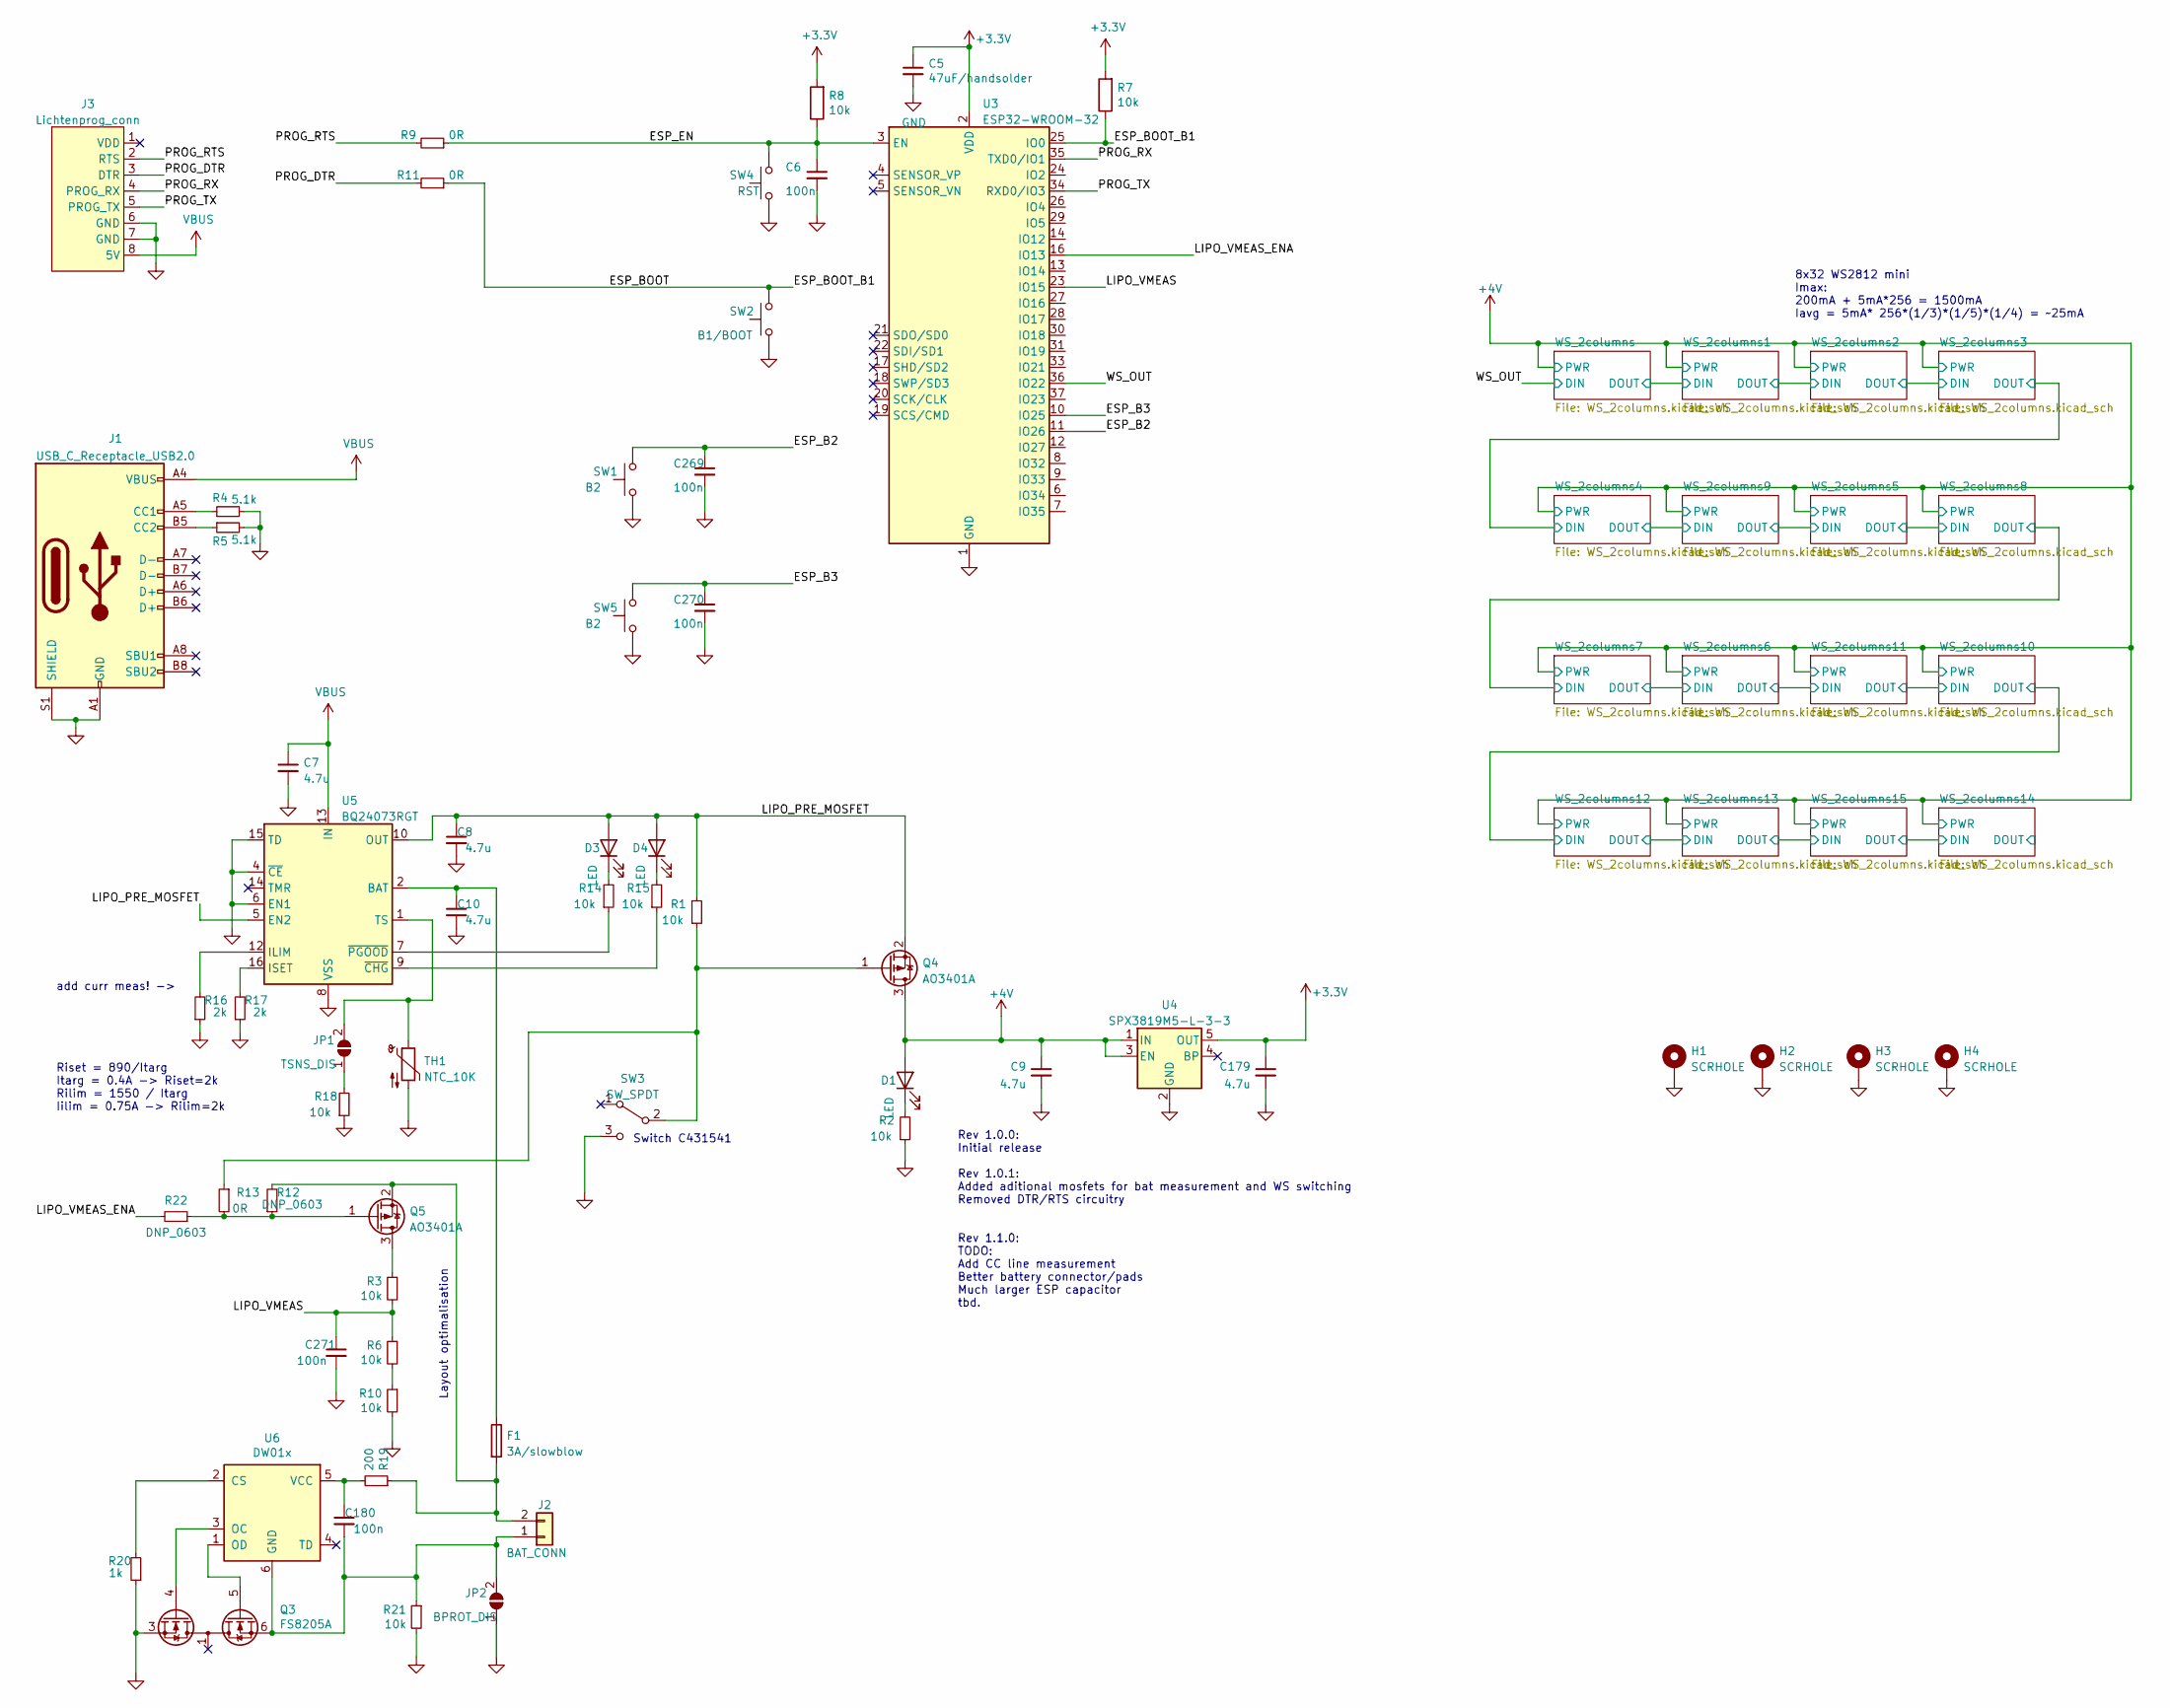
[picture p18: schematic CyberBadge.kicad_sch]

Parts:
C5: 47uF/handsolder; C_1210_3225Metric_Pad1.33x2.70mm_HandSolder
C6, C180, C269, C270, C271: 100n; C_0201_0603Metric
C7, C8, C9, C10, C179: 4.7u; C_0402_1005Metric; LCSC C19702
D1, D3, D4: LED; LED_0603_1608Metric
F1: 3A/slowblow; Fuse_0603_1608Metric_Pad1.05x0.95mm_HandSolder
H1, H2, H3, H4: SCRHOLE; MountingHole_3.2mm_M3
J1: USB_C_Receptacle_USB2.0; USB_C_Receptacle_HRO_TYPE-C-31-M-12; LCSC C165948
J2: BAT_CONN; JST_PH_S2B-PH-K_1x02_P2.00mm_Horizontal
J3: Lichtenprog_conn; Lichtenprog
JP1: TSNS_DIS; SolderJumper-2_P1.3mm_Open_TrianglePad1.0x1.5mm
JP2: BPROT_DIS; SolderJumper-2_P1.3mm_Open_TrianglePad1.0x1.5mm
Q3: FS8205A; TSSOP-8_4.4x3mm_P0.65mm
Q4, Q5: AO3401A; SOT-23
R1, R2, R3, R6, R10, R14, R15, R18, R21: 10k; R_0201_0603Metric; LCSC C25768
R4, R5: 5.1k; R_0201_0603Metric; LCSC C25117
R7, R8: 10k; R_0201_0603Metric
R9, R11, R13: 0R; R_0603_1608Metric_Pad0.98x0.95mm_HandSolder; LCSC C25117
R12, R22: DNP_0603; R_0603_1608Metric_Pad0.98x0.95mm_HandSolder; LCSC C25117
R16, R17: 2k; R_0603_1608Metric_Pad0.98x0.95mm_HandSolder; LCSC C25117
R19: 200; R_0201_0603Metric; LCSC C25768
R20: 1k; R_0201_0603Metric; LCSC C25117
SW1, SW5: B2; SW_SPST_TL3342
SW2: B1/BOOT; SW_SPST_TL3342
SW3: SW_SPDT; SW_SPDT_PCM12
SW4: RST; SW_SPST_FSMSM
TH1: NTC_10K; TestPoint_2Pads_Pitch2.54mm_Drill0.8mm
U3: ESP32-WROOM-32
U4: SPX3819M5-L-3-3; SOT-23-5
U5: BQ24073RGT; VQFN-16-1EP_3x3mm_P0.5mm_EP1.6x1.6mm_ThermalVias
U6: DW01x; SOT-23-6

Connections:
+3.3V: C5.1, C179.1, R7.2, R8.2, U3.2 (VDD), U4.5 (OUT)
+4V: C9.1, D1.2 (A), Q4.3 (D), U4.1 (IN), U4.3 (EN); also elsewhere on the board
/ESP_B2: C269.1, SW1.2, U3.11 (IO26)
/ESP_B3: C270.1, SW5.2, U3.10 (IO25)
/ESP_BOOT: R7.1, R11.1, SW2.2, U3.25 (IO0)
/ESP_EN: C6.1, R8.1, R9.1, SW4.2, U3.3 (EN)
/LIPO_PRE_MOSFET: C8.1, D3.2 (A), D4.2 (A), Q4.2 (S), R1.2, U5.5 (EN2), U5.10 (OUT), U5.11 (OUT)
/LIPO_VMEAS: C271.1, R3.2, R6.1, U3.23 (IO15)
/LIPO_VMEAS_ENA: R22.2, U3.16 (IO13)
/PROG_DTR: J3.3 (DTR), R11.2
/PROG_RTS: J3.2 (RTS), R9.2
/PROG_RX: J3.4 (PROG_RX), U3.35 (TXD0/IO1)
/PROG_TX: J3.5 (PROG_TX), U3.34 (RXD0/IO3)
/WS_OUT: U3.36 (IO22); also elsewhere on the board
GND: C5.2, C6.2, C7.2, C8.2, C9.2, C10.2, C179.2, C269.2, C270.2, C271.2, H1.1, H2.1, H3.1, H4.1, J1.A1 (GND), J1.A12 (GND), J1.B1 (GND), J1.B12 (GND), J1.S1 (SHIELD), J3.6 (GND), J3.7 (GND), JP2.1 (A), Q3.2 (S1), Q3.3 (S1), R2.1, R4.2, R5.2, R10.2, R16.1, R17.1, R18.1, R20.1, R21.2, SW1.1, SW2.1, SW3.3 (C), SW4.1, SW5.1, TH1.2, U3.1 (GND), U3.15 (GND), U3.38 (GND), U3.39 (GND), U4.2 (GND), U5.4 (~CE), U5.6 (EN1), U5.8 (VSS), U5.15 (TD), U5.17 (VSS); also elsewhere on the board
unnamed: C10.1, F1.1, U5.2 (BAT), U5.3 (BAT)
unnamed: D1.1 (K), R2.2
unnamed: D3.1 (K), R14.2
unnamed: D4.1 (K), R15.2
unnamed: J1.A5 (CC1), R4.1
unnamed: J1.B5 (CC2), R5.1
unnamed: C180.2, J2.1, JP2.2 (B), Q3.6 (S2), Q3.7 (S2), R21.1, U6.6 (GND)
unnamed: F1.2, J2.2, Q5.2 (S), R12.2, R19.1
unnamed: JP1.1 (A), R18.2
unnamed: JP1.2 (B), TH1.1, U5.1 (TS)
unnamed: Q3.4 (G1), U6.3 (OC)
unnamed: Q3.5 (G2), U6.1 (OD)
unnamed: Q4.1 (G), R1.1, R13.1, SW3.2 (B)
unnamed: Q5.3 (D), R3.1
unnamed: Q5.1 (G), R12.1, R13.2, R22.1
unnamed: R6.2, R10.1
unnamed: R16.2, U5.12 (ILIM)
unnamed: R17.2, U5.16 (ISET)
unnamed: R15.1, U5.9 (~CHG)
unnamed: R14.1, U5.7 (~PGOOD)
unnamed: R20.2, U6.2 (CS)
unnamed: C180.1, R19.2, U6.5 (VCC)
VBUS: C7.1, J1.A4 (VBUS), J1.A9 (VBUS), J1.B4 (VBUS), J1.B9 (VBUS), J3.8 (5V), U5.13 (IN)

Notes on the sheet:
Switch C431541
Riset = 890/Itarg Itarg = 0.4A -> Riset=2k Rilim = 1550 / Itarg Iilim = 0.75A -> Rilim=2k
8x32 WS2812 mini Imax: 200mA + 5mA*256 = 1500mA Iavg = 5mA* 256*(1/3)*(1/5)*(1/4) = ~25mA
Layout optimalisation
add curr meas! ->
Rev 1.0.0: Initial release Rev 1.0.1: Added aditional mosfets for bat measurement and WS switching Removed DTR/RTS circuitry Rev 1.1.0: TODO: Add CC line measurement Better battery connector/pads Much larger ESP capacitor tbd.

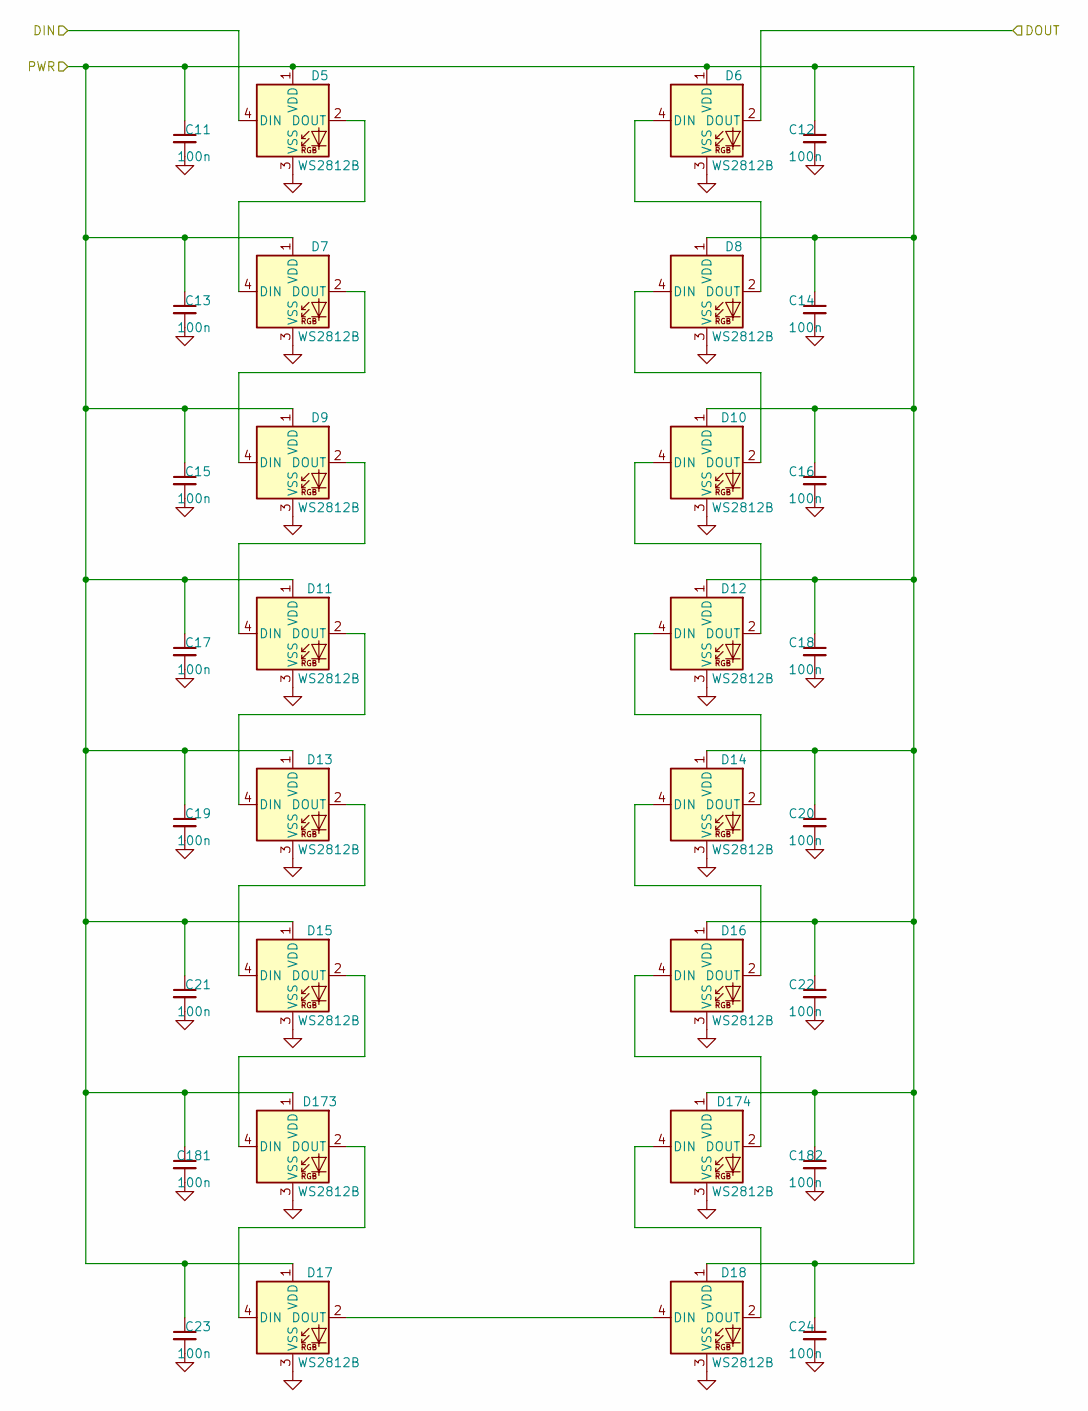
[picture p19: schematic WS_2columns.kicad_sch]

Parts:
C11, C12, C13, C14, C15, C16, C17, C18, C19, C20, C21, C22, C23, C24, C181, C182: 100n; C_0201_0603Metric
D5, D6, D7, D8, D9, D10, D11, D12, D13, D14, D15, D16, D17, D18, D173, D174: WS2812B; LED_WS2812B-2020_pinsRenumbered

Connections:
+4V: C11.1, C12.1, C13.1, C14.1, C15.1, C16.1, C17.1, C18.1, C19.1, C20.1, C21.1, C22.1, C23.1, C24.1, C181.1, C182.1, D5.1 (VDD), D6.1 (VDD), D7.1 (VDD), D8.1 (VDD), D9.1 (VDD), D10.1 (VDD), D11.1 (VDD), D12.1 (VDD), D13.1 (VDD), D14.1 (VDD), D15.1 (VDD), D16.1 (VDD), D17.1 (VDD), D18.1 (VDD), D173.1 (VDD), D174.1 (VDD); also elsewhere on the board
/WS_2columns/DOUT: D6.2 (DOUT); also elsewhere on the board
/WS_OUT: D5.4 (DIN); also elsewhere on the board
GND: C11.2, C12.2, C13.2, C14.2, C15.2, C16.2, C17.2, C18.2, C19.2, C20.2, C21.2, C22.2, C23.2, C24.2, C181.2, C182.2, D5.3 (VSS), D6.3 (VSS), D7.3 (VSS), D8.3 (VSS), D9.3 (VSS), D10.3 (VSS), D11.3 (VSS), D12.3 (VSS), D13.3 (VSS), D14.3 (VSS), D15.3 (VSS), D16.3 (VSS), D17.3 (VSS), D18.3 (VSS), D173.3 (VSS), D174.3 (VSS); also elsewhere on the board
unnamed: D5.2 (DOUT), D7.4 (DIN)
unnamed: D6.4 (DIN), D8.2 (DOUT)
unnamed: D7.2 (DOUT), D9.4 (DIN)
unnamed: D10.4 (DIN), D12.2 (DOUT)
unnamed: D8.4 (DIN), D10.2 (DOUT)
unnamed: D9.2 (DOUT), D11.4 (DIN)
unnamed: D11.2 (DOUT), D13.4 (DIN)
unnamed: D12.4 (DIN), D14.2 (DOUT)
unnamed: D13.2 (DOUT), D15.4 (DIN)
unnamed: D14.4 (DIN), D16.2 (DOUT)
unnamed: D15.2 (DOUT), D173.4 (DIN)
unnamed: D16.4 (DIN), D174.2 (DOUT)
unnamed: D17.4 (DIN), D173.2 (DOUT)
unnamed: D17.2 (DOUT), D18.4 (DIN)
unnamed: D18.2 (DOUT), D174.4 (DIN)

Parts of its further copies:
C25, C26, C27, C28, C29, C30, C31, C32, C33, C34, C35, C36, C37, C38, C39, C40, C41, C42, C43, C44, C45, C46, C47, C48, C49, C50, C51, C52, C53, C54, C55, C56, C57, C58, C59, C60, C61, C62, C63, C64, C65, C66, C67, C68, C69, C70, C71, C72, C73, C74, C75, C76, C77, C78, C79, C80, C81, C82, C83, C84, C85, C86, C87, C88, C89, C90, C91, C92, C93, C94, C95, C96, C97, C98, C99, C100, C101, C102, C103, C104, C105, C106, C107, C108, C109, C110, C111, C112, C113, C114, C115, C116, C117, C118, C119, C120, C121, C122, C123, C124, C125, C126, C127, C128, C129, C130, C131, C132, C133, C134, C135, C136, C137, C138, C139, C140, C141, C142, C143, C144, C145, C146, C147, C148, C149, C150, C151, C152, C153, C154, C155, C156, C157, C158, C159, C160, C161, C162, C163, C164, C165, C166, C167, C168, C169, C170, C171, C172, C173, C174, C175, C176, C177, C178, C183, C184, C185, C186, C187, C188, C189, C190, C191, C192, C193, C194, C195, C196, C197, C198, C199, C200, C201, C202, C203, C204, C205, C206, C207, C208, C209, C210, C211, C212, C213, C214, C215, C216, C217, C218, C219, C220, C221, C222, C223, C224, C225, C226, C227, C228, C229, C230, C231, C232, C233, C234, C235, C236, C237, C238, C239, C240, C241, C242, C243, C244, C245, C246, C247, C248, C249, C250, C251, C252, C253, C254, C255, C256, C257, C258, C259, C260, C261, C262, C263, C264, C265, C266, C267, C268: 100n; C_0201_0603Metric
D19, D20, D21, D22, D23, D24, D25, D26, D27, D28, D29, D30, D31, D32, D33, D34, D35, D36, D37, D38, D39, D40, D41, D42, D43, D44, D45, D46, D47, D48, D49, D50, D51, D52, D53, D54, D55, D56, D57, D58, D59, D60, D61, D62, D63, D64, D65, D66, D67, D68, D69, D70, D71, D72, D73, D74, D75, D76, D77, D78, D79, D80, D81, D82, D83, D84, D85, D86, D87, D88, D89, D90, D91, D92, D93, D94, D95, D96, D97, D98, D99, D100, D101, D102, D103, D104, D105, D106, D107, D108, D109, D110, D111, D112, D113, D114, D115, D116, D117, D118, D119, D120, D121, D122, D123, D124, D125, D126, D127, D128, D129, D130, D131, D132, D133, D134, D135, D136, D137, D138, D139, D140, D141, D142, D143, D144, D145, D146, D147, D148, D149, D150, D151, D152, D153, D154, D155, D156, D157, D158, D159, D160, D161, D162, D163, D164, D165, D166, D167, D168, D169, D170, D171, D172, D175, D176, D177, D178, D179, D180, D181, D182, D183, D184, D185, D186, D187, D188, D189, D190, D191, D192, D193, D194, D195, D196, D197, D198, D199, D200, D201, D202, D203, D204, D205, D206, D207, D208, D209, D210, D211, D212, D213, D214, D215, D216, D217, D218, D219, D220, D221, D222, D223, D224, D225, D226, D227, D228, D229, D230, D231, D232, D233, D234, D235, D236, D237, D238, D239, D240, D241, D242, D243, D244, D245, D246, D247, D248, D249, D250, D251, D252, D253, D254, D255, D256, D257, D258, D259, D260: WS2812B; LED_WS2812B-2020_pinsRenumbered

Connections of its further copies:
+4V: C25.1, C26.1, C27.1, C28.1, C29.1, C30.1, C31.1, C32.1, C33.1, C34.1, C35.1, C36.1, C37.1, C38.1, C39.1, C40.1, C41.1, C42.1, C43.1, C44.1, C45.1, C46.1, C47.1, C48.1, C49.1, C50.1, C51.1, C52.1, C53.1, C54.1, C55.1, C56.1, C57.1, C58.1, C59.1, C60.1, C61.1, C62.1, C63.1, C64.1, C65.1, C66.1, C67.1, C68.1, C69.1, C70.1, C71.1, C72.1, C73.1, C74.1, C75.1, C76.1, C77.1, C78.1, C79.1, C80.1, C81.1, C82.1, C83.1, C84.1, C85.1, C86.1, C87.1, C88.1, C89.1, C90.1, C91.1, C92.1, C93.1, C94.1, C95.1, C96.1, C97.1, C98.1, C99.1, C100.1, C101.1, C102.1, C103.1, C104.1, C105.1, C106.1, C107.1, C108.1, C109.1, C110.1, C111.1, C112.1, C113.1, C114.1, C115.1, C116.1, C117.1, C118.1, C119.1, C120.1, C121.1, C122.1, C123.1, C124.1, C125.1, C126.1, C127.1, C128.1, C129.1, C130.1, C131.1, C132.1, C133.1, C134.1, C135.1, C136.1, C137.1, C138.1, C139.1, C140.1, C141.1, C142.1, C143.1, C144.1, C145.1, C146.1, C147.1, C148.1, C149.1, C150.1, C151.1, C152.1, C153.1, C154.1, C155.1, C156.1, C157.1, C158.1, C159.1, C160.1, C161.1, C162.1, C163.1, C164.1, C165.1, C166.1, C167.1, C168.1, C169.1, C170.1, C171.1, C172.1, C173.1, C174.1, C175.1, C176.1, C177.1, C178.1, C183.1, C184.1, C185.1, C186.1, C187.1, C188.1, C189.1, C190.1, C191.1, C192.1, C193.1, C194.1, C195.1, C196.1, C197.1, C198.1, C199.1, C200.1, C201.1, C202.1, C203.1, C204.1, C205.1, C206.1, C207.1, C208.1, C209.1, C210.1, C211.1, C212.1, C213.1, C214.1, C215.1, C216.1, C217.1, C218.1, C219.1, C220.1, C221.1, C222.1, C223.1, C224.1, C225.1, C226.1, C227.1, C228.1, C229.1, C230.1, C231.1, C232.1, C233.1, C234.1, C235.1, C236.1, C237.1, C238.1, C239.1, C240.1, C241.1, C242.1, C243.1, C244.1, C245.1, C246.1, C247.1, C248.1, C249.1, C250.1, C251.1, C252.1, C253.1, C254.1, C255.1, C256.1, C257.1, C258.1, C259.1, C260.1, C261.1, C262.1, C263.1, C264.1, C265.1, C266.1, C267.1, C268.1, D19.1 (VDD), D20.1 (VDD), D21.1 (VDD), D22.1 (VDD), D23.1 (VDD), D24.1 (VDD), D25.1 (VDD), D26.1 (VDD), D27.1 (VDD), D28.1 (VDD), D29.1 (VDD), D30.1 (VDD), D31.1 (VDD), D32.1 (VDD), D33.1 (VDD), D34.1 (VDD), D35.1 (VDD), D36.1 (VDD), D37.1 (VDD), D38.1 (VDD), D39.1 (VDD), D40.1 (VDD), D41.1 (VDD), D42.1 (VDD), D43.1 (VDD), D44.1 (VDD), D45.1 (VDD), D46.1 (VDD), D47.1 (VDD), D48.1 (VDD), D49.1 (VDD), D50.1 (VDD), D51.1 (VDD), D52.1 (VDD), D53.1 (VDD), D54.1 (VDD), D55.1 (VDD), D56.1 (VDD), D57.1 (VDD), D58.1 (VDD), D59.1 (VDD), D60.1 (VDD), D61.1 (VDD), D62.1 (VDD), D63.1 (VDD), D64.1 (VDD), D65.1 (VDD), D66.1 (VDD), D67.1 (VDD), D68.1 (VDD), D69.1 (VDD), D70.1 (VDD), D71.1 (VDD), D72.1 (VDD), D73.1 (VDD), D74.1 (VDD), D75.1 (VDD), D76.1 (VDD), D77.1 (VDD), D78.1 (VDD), D79.1 (VDD), D80.1 (VDD), D81.1 (VDD), D82.1 (VDD), D83.1 (VDD), D84.1 (VDD), D85.1 (VDD), D86.1 (VDD), D87.1 (VDD), D88.1 (VDD), D89.1 (VDD), D90.1 (VDD), D91.1 (VDD), D92.1 (VDD), D93.1 (VDD), D94.1 (VDD), D95.1 (VDD), D96.1 (VDD), D97.1 (VDD), D98.1 (VDD), D99.1 (VDD), D100.1 (VDD), D101.1 (VDD), D102.1 (VDD), D103.1 (VDD), D104.1 (VDD), D105.1 (VDD), D106.1 (VDD), D107.1 (VDD), D108.1 (VDD), D109.1 (VDD), D110.1 (VDD), D111.1 (VDD), D112.1 (VDD), D113.1 (VDD), D114.1 (VDD), D115.1 (VDD), D116.1 (VDD), D117.1 (VDD), D118.1 (VDD), D119.1 (VDD), D120.1 (VDD), D121.1 (VDD), D122.1 (VDD), D123.1 (VDD), D124.1 (VDD), D125.1 (VDD), D126.1 (VDD), D127.1 (VDD), D128.1 (VDD), D129.1 (VDD), D130.1 (VDD), D131.1 (VDD), D132.1 (VDD), D133.1 (VDD), D134.1 (VDD), D135.1 (VDD), D136.1 (VDD), D137.1 (VDD), D138.1 (VDD), D139.1 (VDD), D140.1 (VDD), D141.1 (VDD), D142.1 (VDD), D143.1 (VDD), D144.1 (VDD), D145.1 (VDD), D146.1 (VDD), D147.1 (VDD), D148.1 (VDD), D149.1 (VDD), D150.1 (VDD), D151.1 (VDD), D152.1 (VDD), D153.1 (VDD), D154.1 (VDD), D155.1 (VDD), D156.1 (VDD), D157.1 (VDD), D158.1 (VDD), D159.1 (VDD), D160.1 (VDD), D161.1 (VDD), D162.1 (VDD), D163.1 (VDD), D164.1 (VDD), D165.1 (VDD), D166.1 (VDD), D167.1 (VDD), D168.1 (VDD), D169.1 (VDD), D170.1 (VDD), D171.1 (VDD), D172.1 (VDD), D175.1 (VDD), D176.1 (VDD), D177.1 (VDD), D178.1 (VDD), D179.1 (VDD), D180.1 (VDD), D181.1 (VDD), D182.1 (VDD), D183.1 (VDD), D184.1 (VDD), D185.1 (VDD), D186.1 (VDD), D187.1 (VDD), D188.1 (VDD), D189.1 (VDD), D190.1 (VDD), D191.1 (VDD), D192.1 (VDD), D193.1 (VDD), D194.1 (VDD), D195.1 (VDD), D196.1 (VDD), D197.1 (VDD), D198.1 (VDD), D199.1 (VDD), D200.1 (VDD), D201.1 (VDD), D202.1 (VDD), D203.1 (VDD), D204.1 (VDD), D205.1 (VDD), D206.1 (VDD), D207.1 (VDD), D208.1 (VDD), D209.1 (VDD), D210.1 (VDD), D211.1 (VDD), D212.1 (VDD), D213.1 (VDD), D214.1 (VDD), D215.1 (VDD), D216.1 (VDD), D217.1 (VDD), D218.1 (VDD), D219.1 (VDD), D220.1 (VDD), D221.1 (VDD), D222.1 (VDD), D223.1 (VDD), D224.1 (VDD), D225.1 (VDD), D226.1 (VDD), D227.1 (VDD), D228.1 (VDD), D229.1 (VDD), D230.1 (VDD), D231.1 (VDD), D232.1 (VDD), D233.1 (VDD), D234.1 (VDD), D235.1 (VDD), D236.1 (VDD), D237.1 (VDD), D238.1 (VDD), D239.1 (VDD), D240.1 (VDD), D241.1 (VDD), D242.1 (VDD), D243.1 (VDD), D244.1 (VDD), D245.1 (VDD), D246.1 (VDD), D247.1 (VDD), D248.1 (VDD), D249.1 (VDD), D250.1 (VDD), D251.1 (VDD), D252.1 (VDD), D253.1 (VDD), D254.1 (VDD), D255.1 (VDD), D256.1 (VDD), D257.1 (VDD), D258.1 (VDD), D259.1 (VDD), D260.1 (VDD); also elsewhere on the board
/WS_2columns1/DOUT: D20.2 (DOUT), D33.4 (DIN)
/WS_2columns2/DOUT: D34.2 (DOUT), D47.4 (DIN)
/WS_2columns3/DOUT: D48.2 (DOUT), D61.4 (DIN)
/WS_2columns4/DOUT: D62.2 (DOUT), D75.4 (DIN)
/WS_2columns5/DIN: D76.2 (DOUT), D89.4 (DIN)
/WS_2columns5/DOUT: D90.2 (DOUT), D103.4 (DIN)
/WS_2columns6/DIN: D118.2 (DOUT), D131.4 (DIN)
/WS_2columns7/DIN: D104.2 (DOUT), D117.4 (DIN)
/WS_2columns10/DIN: D146.2 (DOUT), D159.4 (DIN)
/WS_2columns10/DOUT: D160.2 (DOUT), D197.4 (DIN)
/WS_2columns11/DIN: D132.2 (DOUT), D145.4 (DIN)
/WS_2columns12/DOUT: D198.2 (DOUT), D213.4 (DIN)
/WS_2columns13/DOUT: D214.2 (DOUT), D229.4 (DIN)
/WS_2columns14/DIN: D230.2 (DOUT), D245.4 (DIN)
/WS_2columns14/DOUT: D246.2 (DOUT)
/WS_2columns/DOUT: D19.4 (DIN); also elsewhere on the board
GND: C25.2, C26.2, C27.2, C28.2, C29.2, C30.2, C31.2, C32.2, C33.2, C34.2, C35.2, C36.2, C37.2, C38.2, C39.2, C40.2, C41.2, C42.2, C43.2, C44.2, C45.2, C46.2, C47.2, C48.2, C49.2, C50.2, C51.2, C52.2, C53.2, C54.2, C55.2, C56.2, C57.2, C58.2, C59.2, C60.2, C61.2, C62.2, C63.2, C64.2, C65.2, C66.2, C67.2, C68.2, C69.2, C70.2, C71.2, C72.2, C73.2, C74.2, C75.2, C76.2, C77.2, C78.2, C79.2, C80.2, C81.2, C82.2, C83.2, C84.2, C85.2, C86.2, C87.2, C88.2, C89.2, C90.2, C91.2, C92.2, C93.2, C94.2, C95.2, C96.2, C97.2, C98.2, C99.2, C100.2, C101.2, C102.2, C103.2, C104.2, C105.2, C106.2, C107.2, C108.2, C109.2, C110.2, C111.2, C112.2, C113.2, C114.2, C115.2, C116.2, C117.2, C118.2, C119.2, C120.2, C121.2, C122.2, C123.2, C124.2, C125.2, C126.2, C127.2, C128.2, C129.2, C130.2, C131.2, C132.2, C133.2, C134.2, C135.2, C136.2, C137.2, C138.2, C139.2, C140.2, C141.2, C142.2, C143.2, C144.2, C145.2, C146.2, C147.2, C148.2, C149.2, C150.2, C151.2, C152.2, C153.2, C154.2, C155.2, C156.2, C157.2, C158.2, C159.2, C160.2, C161.2, C162.2, C163.2, C164.2, C165.2, C166.2, C167.2, C168.2, C169.2, C170.2, C171.2, C172.2, C173.2, C174.2, C175.2, C176.2, C177.2, C178.2, C183.2, C184.2, C185.2, C186.2, C187.2, C188.2, C189.2, C190.2, C191.2, C192.2, C193.2, C194.2, C195.2, C196.2, C197.2, C198.2, C199.2, C200.2, C201.2, C202.2, C203.2, C204.2, C205.2, C206.2, C207.2, C208.2, C209.2, C210.2, C211.2, C212.2, C213.2, C214.2, C215.2, C216.2, C217.2, C218.2, C219.2, C220.2, C221.2, C222.2, C223.2, C224.2, C225.2, C226.2, C227.2, C228.2, C229.2, C230.2, C231.2, C232.2, C233.2, C234.2, C235.2, C236.2, C237.2, C238.2, C239.2, C240.2, C241.2, C242.2, C243.2, C244.2, C245.2, C246.2, C247.2, C248.2, C249.2, C250.2, C251.2, C252.2, C253.2, C254.2, C255.2, C256.2, C257.2, C258.2, C259.2, C260.2, C261.2, C262.2, C263.2, C264.2, C265.2, C266.2, C267.2, C268.2, D19.3 (VSS), D20.3 (VSS), D21.3 (VSS), D22.3 (VSS), D23.3 (VSS), D24.3 (VSS), D25.3 (VSS), D26.3 (VSS), D27.3 (VSS), D28.3 (VSS), D29.3 (VSS), D30.3 (VSS), D31.3 (VSS), D32.3 (VSS), D33.3 (VSS), D34.3 (VSS), D35.3 (VSS), D36.3 (VSS), D37.3 (VSS), D38.3 (VSS), D39.3 (VSS), D40.3 (VSS), D41.3 (VSS), D42.3 (VSS), D43.3 (VSS), D44.3 (VSS), D45.3 (VSS), D46.3 (VSS), D47.3 (VSS), D48.3 (VSS), D49.3 (VSS), D50.3 (VSS), D51.3 (VSS), D52.3 (VSS), D53.3 (VSS), D54.3 (VSS), D55.3 (VSS), D56.3 (VSS), D57.3 (VSS), D58.3 (VSS), D59.3 (VSS), D60.3 (VSS), D61.3 (VSS), D62.3 (VSS), D63.3 (VSS), D64.3 (VSS), D65.3 (VSS), D66.3 (VSS), D67.3 (VSS), D68.3 (VSS), D69.3 (VSS), D70.3 (VSS), D71.3 (VSS), D72.3 (VSS), D73.3 (VSS), D74.3 (VSS), D75.3 (VSS), D76.3 (VSS), D77.3 (VSS), D78.3 (VSS), D79.3 (VSS), D80.3 (VSS), D81.3 (VSS), D82.3 (VSS), D83.3 (VSS), D84.3 (VSS), D85.3 (VSS), D86.3 (VSS), D87.3 (VSS), D88.3 (VSS), D89.3 (VSS), D90.3 (VSS), D91.3 (VSS), D92.3 (VSS), D93.3 (VSS), D94.3 (VSS), D95.3 (VSS), D96.3 (VSS), D97.3 (VSS), D98.3 (VSS), D99.3 (VSS), D100.3 (VSS), D101.3 (VSS), D102.3 (VSS), D103.3 (VSS), D104.3 (VSS), D105.3 (VSS), D106.3 (VSS), D107.3 (VSS), D108.3 (VSS), D109.3 (VSS), D110.3 (VSS), D111.3 (VSS), D112.3 (VSS), D113.3 (VSS), D114.3 (VSS), D115.3 (VSS), D116.3 (VSS), D117.3 (VSS), D118.3 (VSS), D119.3 (VSS), D120.3 (VSS), D121.3 (VSS), D122.3 (VSS), D123.3 (VSS), D124.3 (VSS), D125.3 (VSS), D126.3 (VSS), D127.3 (VSS), D128.3 (VSS), D129.3 (VSS), D130.3 (VSS), D131.3 (VSS), D132.3 (VSS), D133.3 (VSS), D134.3 (VSS), D135.3 (VSS), D136.3 (VSS), D137.3 (VSS), D138.3 (VSS), D139.3 (VSS), D140.3 (VSS), D141.3 (VSS), D142.3 (VSS), D143.3 (VSS), D144.3 (VSS), D145.3 (VSS), D146.3 (VSS), D147.3 (VSS), D148.3 (VSS), D149.3 (VSS), D150.3 (VSS), D151.3 (VSS), D152.3 (VSS), D153.3 (VSS), D154.3 (VSS), D155.3 (VSS), D156.3 (VSS), D157.3 (VSS), D158.3 (VSS), D159.3 (VSS), D160.3 (VSS), D161.3 (VSS), D162.3 (VSS), D163.3 (VSS), D164.3 (VSS), D165.3 (VSS), D166.3 (VSS), D167.3 (VSS), D168.3 (VSS), D169.3 (VSS), D170.3 (VSS), D171.3 (VSS), D172.3 (VSS), D175.3 (VSS), D176.3 (VSS), D177.3 (VSS), D178.3 (VSS), D179.3 (VSS), D180.3 (VSS), D181.3 (VSS), D182.3 (VSS), D183.3 (VSS), D184.3 (VSS), D185.3 (VSS), D186.3 (VSS), D187.3 (VSS), D188.3 (VSS), D189.3 (VSS), D190.3 (VSS), D191.3 (VSS), D192.3 (VSS), D193.3 (VSS), D194.3 (VSS), D195.3 (VSS), D196.3 (VSS), D197.3 (VSS), D198.3 (VSS), D199.3 (VSS), D200.3 (VSS), D201.3 (VSS), D202.3 (VSS), D203.3 (VSS), D204.3 (VSS), D205.3 (VSS), D206.3 (VSS), D207.3 (VSS), D208.3 (VSS), D209.3 (VSS), D210.3 (VSS), D211.3 (VSS), D212.3 (VSS), D213.3 (VSS), D214.3 (VSS), D215.3 (VSS), D216.3 (VSS), D217.3 (VSS), D218.3 (VSS), D219.3 (VSS), D220.3 (VSS), D221.3 (VSS), D222.3 (VSS), D223.3 (VSS), D224.3 (VSS), D225.3 (VSS), D226.3 (VSS), D227.3 (VSS), D228.3 (VSS), D229.3 (VSS), D230.3 (VSS), D231.3 (VSS), D232.3 (VSS), D233.3 (VSS), D234.3 (VSS), D235.3 (VSS), D236.3 (VSS), D237.3 (VSS), D238.3 (VSS), D239.3 (VSS), D240.3 (VSS), D241.3 (VSS), D242.3 (VSS), D243.3 (VSS), D244.3 (VSS), D245.3 (VSS), D246.3 (VSS), D247.3 (VSS), D248.3 (VSS), D249.3 (VSS), D250.3 (VSS), D251.3 (VSS), D252.3 (VSS), D253.3 (VSS), D254.3 (VSS), D255.3 (VSS), D256.3 (VSS), D257.3 (VSS), D258.3 (VSS), D259.3 (VSS), D260.3 (VSS); also elsewhere on the board
unnamed: D19.2 (DOUT), D21.4 (DIN)
unnamed: D20.4 (DIN), D22.2 (DOUT)
unnamed: D21.2 (DOUT), D23.4 (DIN)
unnamed: D22.4 (DIN), D24.2 (DOUT)
unnamed: D23.2 (DOUT), D25.4 (DIN)
unnamed: D24.4 (DIN), D26.2 (DOUT)
unnamed: D25.2 (DOUT), D27.4 (DIN)
unnamed: D26.4 (DIN), D28.2 (DOUT)
unnamed: D27.2 (DOUT), D29.4 (DIN)
unnamed: D28.4 (DIN), D30.2 (DOUT)
unnamed: D31.2 (DOUT), D32.4 (DIN)
unnamed: D33.2 (DOUT), D35.4 (DIN)
unnamed: D34.4 (DIN), D36.2 (DOUT)
unnamed: D35.2 (DOUT), D37.4 (DIN)
unnamed: D36.4 (DIN), D38.2 (DOUT)
unnamed: D37.2 (DOUT), D39.4 (DIN)
unnamed: D38.4 (DIN), D40.2 (DOUT)
unnamed: D39.2 (DOUT), D41.4 (DIN)
unnamed: D40.4 (DIN), D42.2 (DOUT)
unnamed: D41.2 (DOUT), D43.4 (DIN)
unnamed: D42.4 (DIN), D44.2 (DOUT)
unnamed: D45.2 (DOUT), D46.4 (DIN)
unnamed: D47.2 (DOUT), D49.4 (DIN)
unnamed: D48.4 (DIN), D50.2 (DOUT)
unnamed: D49.2 (DOUT), D51.4 (DIN)
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

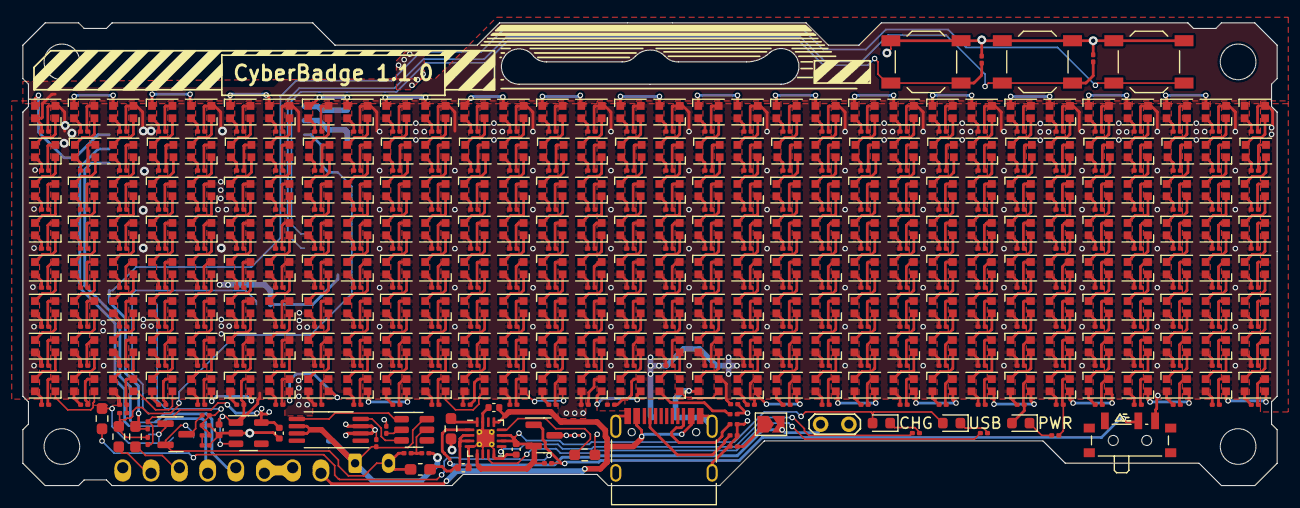
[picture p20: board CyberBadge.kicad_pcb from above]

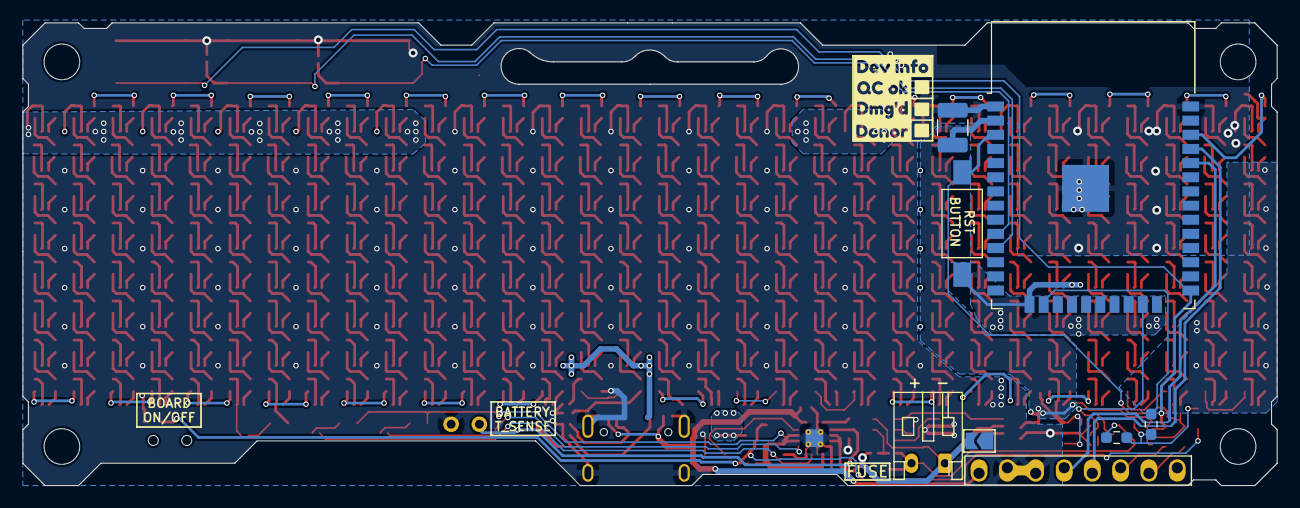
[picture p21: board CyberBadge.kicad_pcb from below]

Board: 2 copper layers, 112.5 x 41.5 mm, 575 parts (12 on the bottom side), 293 nets.

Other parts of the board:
kibuzzard-6394C46A: G***; kibuzzard-6394C46A
kibuzzard-6394C47E: G***; kibuzzard-6394C47E
kibuzzard-6394C445: G***; kibuzzard-6394C445
kibuzzard-6394C560: G***; kibuzzard-6394C560

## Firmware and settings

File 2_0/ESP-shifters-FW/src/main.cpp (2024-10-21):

#include <Arduino.h>
#include "pinDefs.h"


class BootlegDumbMatrix {
public:

  int oe;
  int latch;
  int clock;
  int data;

  int rowCount;
  int *rowPins;

  BootlegDumbMatrix(){};

  void init(){
    pinMode(oe, OUTPUT);
    pinMode(latch, OUTPUT);
    pinMode(clock, OUTPUT);
    pinMode(data, OUTPUT);

    for (int i = 0; i < rowCount; i++) {
      pinMode(rowPins[i], OUTPUT);
      digitalWrite(rowPins[i], HIGH);
    }

    digitalWrite(oe, LOW);
  }

  void setRow(int row) {
    for (int i = 0; i < rowCount; i++) {
      digitalWrite(rowPins[i], HIGH);
    }
    if (row > rowCount) {
      return;
    }
    digitalWrite(rowPins[row], LOW);
  }

  void shiftOut(uint8_t val) {
    uint8_t i;

    for (i = 0; i < 8; i++)  {
      digitalWrite(data, !!(val & (1 << i)));
      
      digitalWrite(clock, HIGH);
      digitalWrite(clock, LOW);
    }
  }

  uint8_t lineBuffer[12];

  void spewBuf(){
    for (int i = 0; i < 12; i++) {
      shiftOut(lineBuffer[i]);
    }
  }

  void drawRow(int rowNum){
    setRow(rowNum);


    delayMicroseconds(100);
    digitalWrite(LATCH_PIN, LOW);
    // delay(1);
    digitalWrite(LATCH_PIN, HIGH);
  }

  void drawFrame(){
    for (int line = 0; line < 1; line++) {
      // uint8_t *pattern = {0xff, 0xff, 0xff, 0xff, 0xff, 0xff, 0xff, 0xff, 0xff, 0xff, 0xff, 0xff};
      for (int i = 0; i < 12; i++) {
        lineBuffer[i] =getGreenPattern(i+2);
      }
      spewBuf();
      drawRow(line);
      sleep(1);
    }
  }

  uint8_t getGreenPattern(int i){
    switch (i%3){
      case 0:
        return 0b01001001;
      case 1:
        return 0b10010010;
      default:
        return 0b00100100;
    }
  }

};

BootlegDumbMatrix dmatrix = BootlegDumbMatrix();

void setup() {

  dmatrix.oe = OE_PIN;
  dmatrix.latch = LATCH_PIN;
  dmatrix.clock = CLOCK_PIN;
  dmatrix.data = DATA_PIN;
  dmatrix.rowCount = 8;
  dmatrix.rowPins = new int[8];
  memcpy(dmatrix.rowPins, ROW_PINS, 8*sizeof(int));
  // dmatrix.rowPins = ROW_PINS;
  dmatrix.init();

  Serial.begin(115200);
}

int counter = 0;
int delayVal = 15000;

void loop() {
  dmatrix.drawFrame();
  
}

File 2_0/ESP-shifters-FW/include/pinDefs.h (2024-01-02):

#pragma once

const int BUTTON_PIN_1 = 0;
const int BUTTON_PIN_2 = 26;
const int BUTTON_PIN_3 = 25;

const int PIN_WS2812 = 22;




const int DATA_PIN =  13;
const int CLOCK_PIN =  22;
const int LATCH_PIN =  23;
const int OE_PIN =  19;

const int ROW1_PIN =  15;
const int ROW2_PIN =  17;
const int ROW3_PIN =  0;
const int ROW4_PIN =  16;
const int ROW5_PIN =  4;
const int ROW6_PIN =  12;
const int ROW7_PIN =  18;
const int ROW8_PIN =  5;

const int ROW_PINS[8] = {
    ROW1_PIN, ROW2_PIN, ROW3_PIN, ROW4_PIN,
    ROW5_PIN, ROW6_PIN, ROW7_PIN, ROW8_PIN
};

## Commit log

2022-11-26 add fiels
    [CyberBadge.kicad_pcb, CyberBadge.kicad_sch]
2023-01-03 some layout fiddling, but the schematic is not ready yet
    [CyberBadge.kicad_pcb, CyberBadge.kicad_sch, WS_2columns.kicad_sch]
2023-01-07 i forgor
    [CyberBadge.kicad_pcb, CyberBadge.kicad_sch]
2023-01-09 Add OpenSCAD project
    [diffuser.scad]
2023-01-09 Add STL and 3MF
    [diffuser.3mf, diffuser.stl]
2023-01-13 change pixel count
    [CyberBadge.kicad_pcb, CyberBadge.kicad_sch, WS_2columns.kicad_sch]
2023-01-15 commit before replicatelayout
    [CyberBadge.kicad_pcb, CyberBadge.kicad_sch]
2023-01-17 routing and shape definiton in progress
    [CyberBadge.kicad_pcb, CyberBadge.kicad_sch]
2023-01-19 add changes for review
    [CyberBadge.kicad_pcb, CyberBadge.kicad_sch]
2023-01-24 most of routing
    [CyberBadge.kicad_pcb, CyberBadge.kicad_sch]
2023-01-25 blah blah routing planes
    [CyberBadge.kicad_pcb, CyberBadge.kicad_sch]
2023-01-28 fix usb sw schematic, fix rev on silk
2023-01-29 routin sroutin, add bom
    [CyberBadge.kicad_sch, bom.csv]
2023-01-30 add production stuff
    [CyberBadge-job.gbrjob, top-pos-jlc.csv]
2023-02-04 fix dumb bom
    [bom.csv]
2023-02-19 Fitting diffuser
    [diffuser.3mf, diffuser.scad, diffuser.stl]
2023-02-26 schematic cleanup, add PDF and 3D model
    [CyberBadge.kicad_sch, WS_2columns.kicad_sch]
2023-02-26 pin description in readme
2023-02-27 Add backcover
    [back.3mf, back.stl, backcover.scad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]
2023-02-27 backcover: Bigger strap hole
    [back.stl, backcover.scad, backcover.stl]
2023-03-11 Fat back
    [back.3mf, backcover.3mf, backcover.scad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]
2023-03-13 Not sure how to track commit id in file
    [backcover.3mf, backcover.scad, backcover.stl]
2023-04-17 move to kicad7, tweaks for second production run
    [CyberBadge.kicad_sch, WS_2columns.kicad_sch]
2023-04-17 commit before editing project in notepad lmao
    [CyberBadge.kicad_pcb]
2023-05-08 added pre-commit hook
    [backcover.3mf, backcover.scad, diffuser.3mf]
2023-05-08 Git hook test
    [backcover-fat.stl]
2023-05-08 Add funny script
    [backcover.scad]
2023-05-08 Fix hook
    [commit.scad]
2023-05-08 Huh, something stupid
    [backcover.scad]
2023-05-08 Increase button height
    [backcover.scad, commit.scad, diffuser.scad]
2023-05-08 Add new stl
    [diffuser.stl]
2023-05-09 Forgor STL
    [backcover.stl, commit.scad, diffuser.scad]
2023-09-01 add files for 2.0
    [BOM-ledboad.csv, CyberBadge.kicad_pcb, CyberBadge.kicad_sch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]
2023-09-01 cleanup 3d i guess
    [backcover m3.3mf, backcover-fat.stl, backcover.3mf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]
2024-10-14 save before next rev
    [ledboad.kicad_pcb, ledboad.kicad_sch]
2024-10-15 commit before rescheme
    [ledboad.kicad_pcb, ledboad.kicad_sch, ledboad.step]
2024-10-21 rescheme, reroute
    [PMOS.kicad_sch, ledboad.kicad_pcb, ledboad.kicad_sch]
2024-10-27 work on ledboard
    [ledboad.kicad_pcb, ledboad.kicad_sch]
2024-11-03 before oder
    [PMOS.kicad_sch, ledboad.kicad_pcb, ledboad.kicad_sch]
